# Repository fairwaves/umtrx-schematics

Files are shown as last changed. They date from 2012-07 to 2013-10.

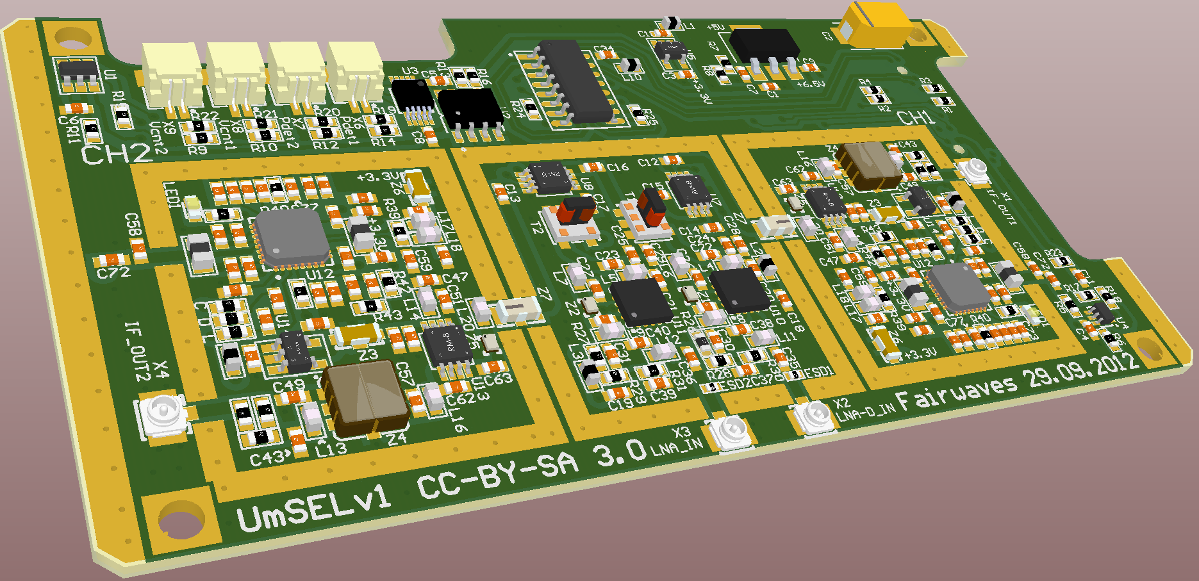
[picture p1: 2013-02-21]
umsel-v1/pictures/UmSELv1-TOP.png

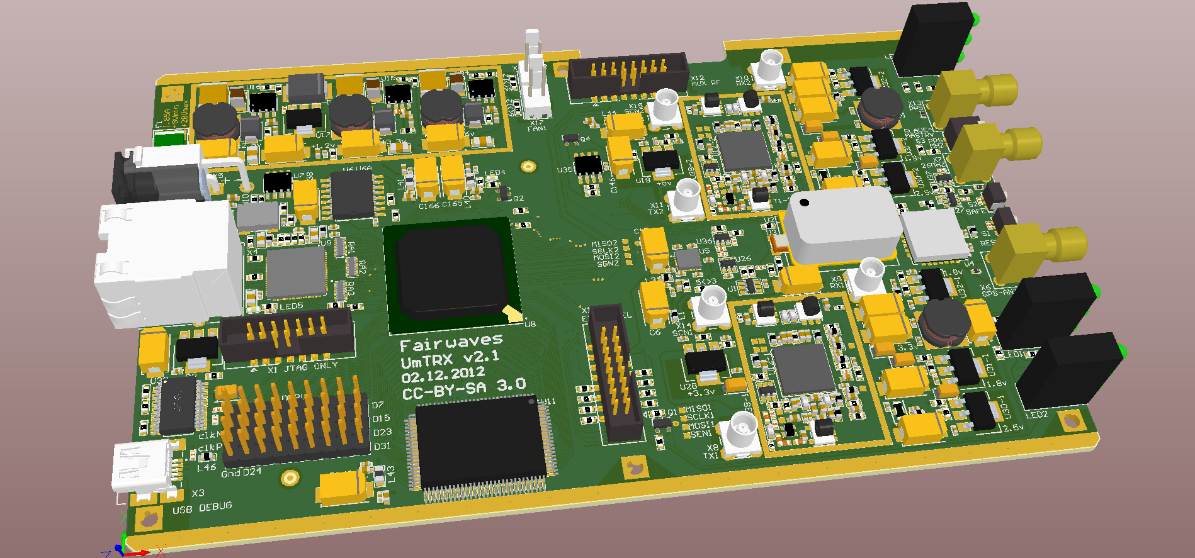
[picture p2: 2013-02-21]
umtrx-v2.1/pictures/UmTRXv21_all_comp.png

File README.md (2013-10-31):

Schematics and accompanying documentation for the UmTRX project
===============================================================

UmTRX is a dual-channel wide-band SDR transceiver with 1GbE connection. It is developed by [Fairwaves] team to be used as a transceiver for [OpenBTS] and [OsmoBTS] GSM base stations, but due to its SDR nature it could be used for many other applications as well.

For more details visit the project web-site: http://code.google.com/p/umtrx/

[Fairwaves]: http://www.fairwaves.ru/
[OpenBTS]: https://wush.net/trac/rangepublic/
[OsmoBTS]: http://openbsc.osmocom.org/trac/wiki/OsmoBTS

Structure
---------

- umtrx-v2 - files related to UmTRXv2 boards
  - altium - design files in Altium Designer format
  - bom - Bill of Materials exported from the Altium Designer
  - pdf - schematics and assembly drawings exported from the Altium Designer
  - pictures - 3D model pictures and photos
- umtrx-v2.1 - files related to UmTRXv2.1 boards
  - altium - design files in Altium Designer format
  - bom - Bill of Materials exported from the Altium Designer
  - pdf - schematics and assembly drawings exported from the Altium Designer
  - pictures - 3D model pictures and photos
- umsel-v1 - files related to UmSELv1 preselector mezzanine boards (GSM900 and GSM1800 versions)
  - altium - design files in Altium Designer format
  - bom - Bill of Materials exported from the Altium Designer
  - gerber - PCB layout in the Gerber format
  - NC Drill - drill files for manufacturing
  - pdf - schematics and assembly drawings exported from the Altium Designer
  - Pick Place - pick and place files for manufacturing
  - pictures - 3D model pictures and photos

Note: PCB layout for new UmTRX versions are published when we start selling this version. Prior to that it's available per request to our partners.

License
-------

All design files, including schematics and PCB layout are licensed under Creative Commons Attribution-ShareAlike 3.0 license [CC-BY-SA 3.0].

In few words, it means, that you're free to copy, distribute and adapt the work both for commercial and non-commercial use, under the condition that you attribute the original project and distribute the derived work under the same or a compatible license.

For a full legal text of the license please refer to the [Creative Commons web-site][CC-BY-SA 3.0].

**Note**: We're looking at the [CERN Open Hardware License][OHL] and will probably switch to it when dust settles around it a bit.

[CC-BY-SA 3.0]: http://creativecommons.org/licenses/by-sa/3.0/
[OHL]: http://www.ohwr.org/projects/cernohl/wiki/

Datasheets
----------

* Most datasheet are easily found at the respective manufacturers' web-sites.
* Datasheets for Lime Microsystems LMS6002D single-chip transceiver could be found at the Myriad-RF project LMS6002D-Docs GitHub repository: https://github.com/myriadrf/LMS6002D-docs

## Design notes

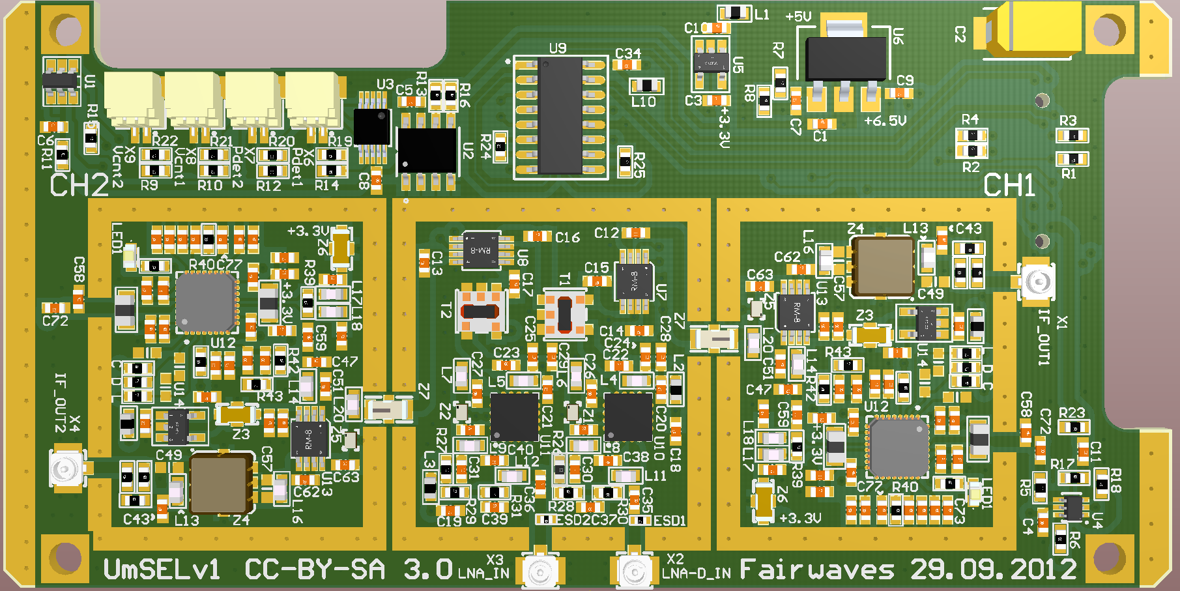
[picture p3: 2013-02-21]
umsel-v1/pictures/UmSELv1-TOP-1800.png

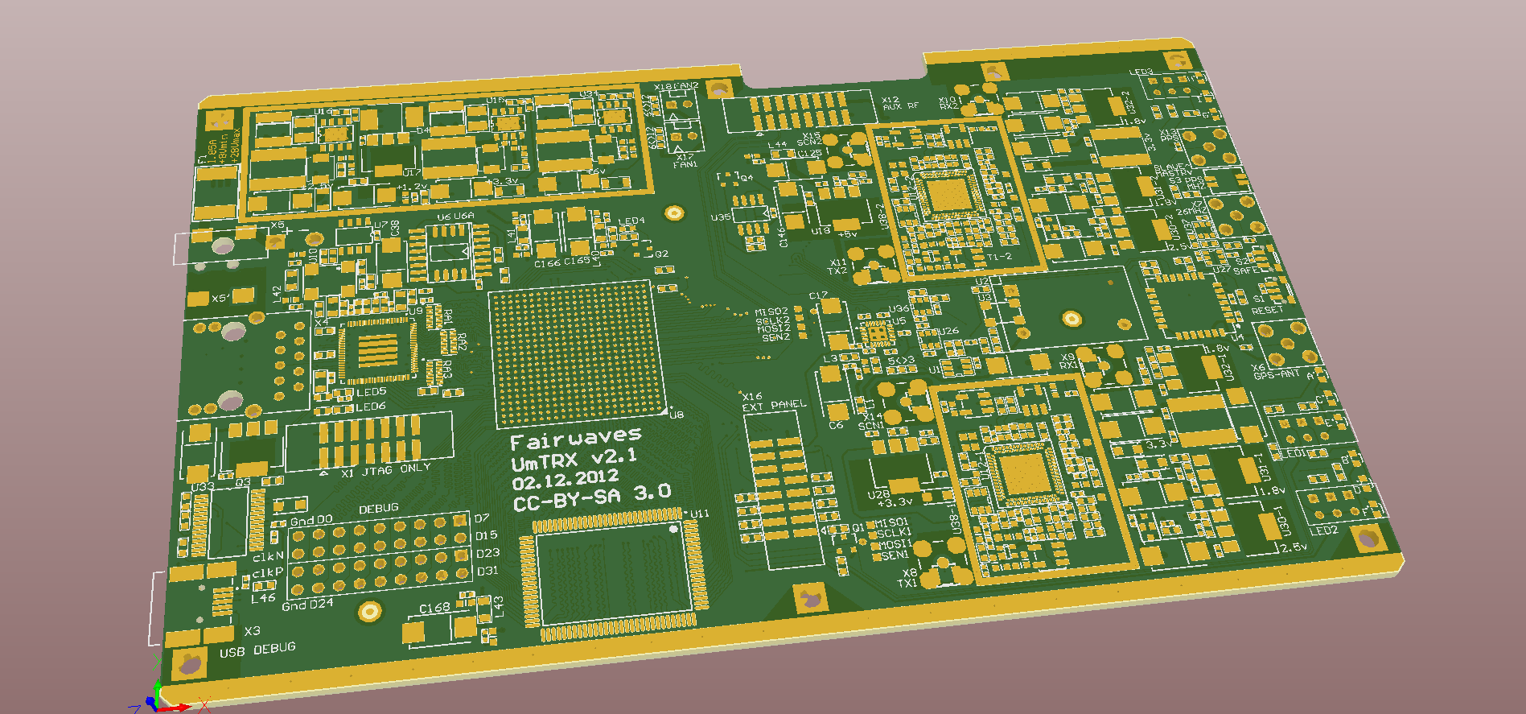
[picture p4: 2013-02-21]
umtrx-v2.1/pictures/UmTRXv21_empty.png

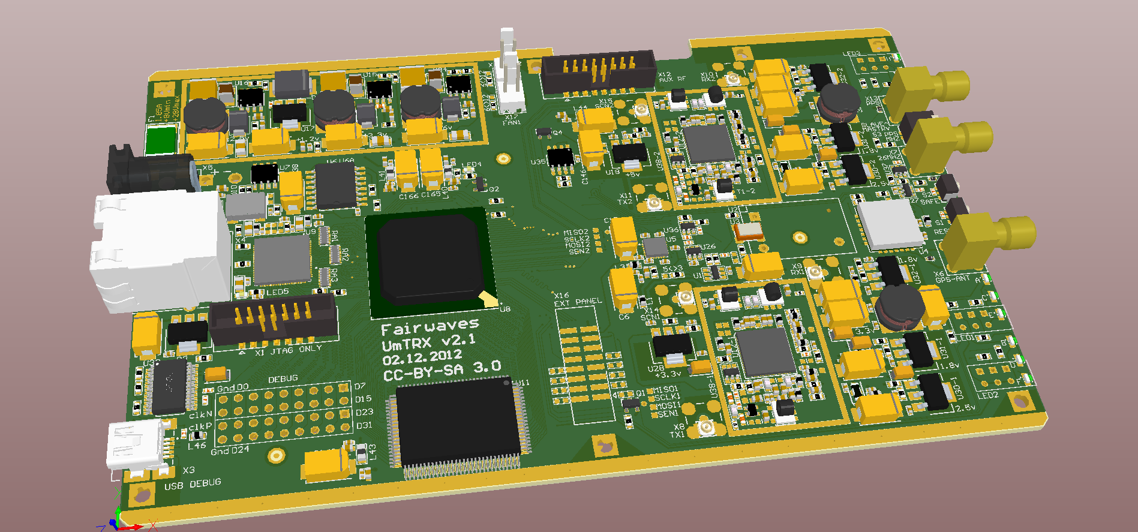
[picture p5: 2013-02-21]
umtrx-v2.1/pictures/UmTRXv21_20dBm_TCXO.png

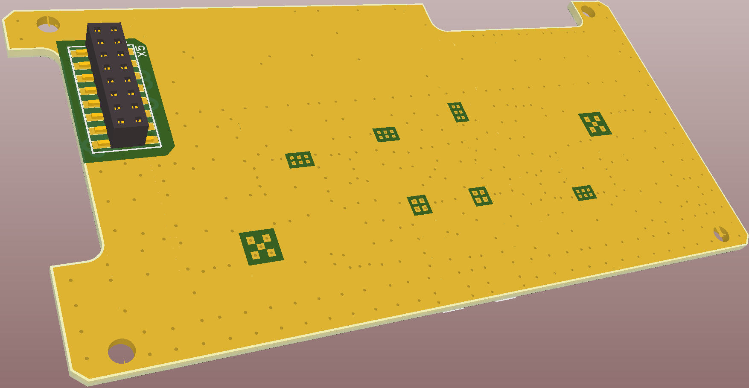
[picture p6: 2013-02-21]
umsel-v1/pictures/UmSELv1-BOT.png

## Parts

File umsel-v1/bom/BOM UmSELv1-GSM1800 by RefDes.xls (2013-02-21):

Designator | Value | Name | Description | Footprint
C1 | 0.1 | SMD0603 | Capacitor | C0603-Phillips
C2 | 100uF | CASE-D | Capacitor | cd7343
C3 | 1uF | SMD0603 | Capacitor | C0603-Phillips
C4 | 0.1 | SMD0603 | Capacitor | C0603-Phillips
C5 | 0.1 | SMD0603 | Capacitor | C0603-Phillips
C6 | 0.1 | SMD0603 | Capacitor | C0603-Phillips
C7 | 0.01 | SMD0603 | Capacitor | C0603-Phillips
C8 | 0.1 | SMD0603 | Capacitor | C0603-Phillips
C9 | 1uF | SMD0603 | Capacitor | C0603-Phillips
C10 | 1uF | SMD0603 | Capacitor | C0603-Phillips
C11 | 0.01 | SMD0603 | Capacitor | C0603-Phillips
C12 | 10p | SMD0603 | Capacitor | C0603-PHILLIPS
C13 | 10p | SMD0603 | Capacitor | C0603-PHILLIPS
C14 | 10p | SMD0603 | Capacitor | C0603-PHILLIPS
C15 | 10p | SMD0603 | Capacitor | C0603-PHILLIPS
C16 | 10p | SMD0603 | Capacitor | C0603-PHILLIPS
C17 | 10p | SMD0603 | Capacitor | C0603-PHILLIPS
C18 | 0.1 | SMD0603 | Capacitor | C0603-Phillips
C19 | 0.1 | SMD0603 | Capacitor | C0603-Phillips
C20 | 3.3p | SMD0603 | Capacitor | C0603-PHILLIPS
C21 | 3.3p | SMD0603 | Capacitor | C0603-PHILLIPS
C22 | 100p | SMD0603 | Capacitor | C0603-PHILLIPS
C23 | 100p | SMD0603 | Capacitor | C0603-PHILLIPS
C24 | 0.1 | SMD0603 | Capacitor | C0603-Phillips
C25 | 0.1 | SMD0603 | Capacitor | C0603-Phillips
C26 | 10p | SMD0603 | Capacitor | C0603-PHILLIPS
C27 | 10p | SMD0603 | Capacitor | C0603-PHILLIPS
C28 | 4.7uF | SMD0603 | Capacitor | C0603-Phillips
C29 | 4.7uF | SMD0603 | Capacitor | C0603-Phillips
C30 | 10p | SMD0603 | Capacitor | C0603-PHILLIPS
C31 | 10p | SMD0603 | Capacitor | C0603-PHILLIPS
C32 | 1000p | SMD0603 | Capacitor | C0603-PHILLIPS
C33 | 1000p | SMD0603 | Capacitor | C0603-PHILLIPS
C34 | 0.1 | SMD0603 | Capacitor | C0603-Phillips
C35 | 10p | SMD0603 | Capacitor | C0603-PHILLIPS
C36 | 10p | SMD0603 | Capacitor | C0603-PHILLIPS
C37 | 4.7uF | SMD0603 | Capacitor | C0603-Phillips
C38 | 10p | SMD0603 | Capacitor | C0603-Phillips
C39 | 4.7uF | SMD0603 | Capacitor | C0603-Phillips
C40 | 10p | SMD0603 | Capacitor | C0603-Phillips
C43 | 3.3pF | SMD0603 | Capacitor | C0603-Phillips
C43" | 3.3pF | SMD0603 | Capacitor | C0603-Phillips
C45 | 0.1 | SMD0603 | Capacitor | C0603-Phillips
C45" | 0.1 | SMD0603 | Capacitor | C0603-Phillips
C46 | 10p | SMD0603 | Capacitor | C0603-Phillips
C46" | 10p | SMD0603 | Capacitor | C0603-Phillips
C47 | 3p | SMD0603 | Capacitor | C0603-Phillips
C47" | 3p | SMD0603 | Capacitor | C0603-Phillips
C48 | 3300p | SMD0603 | Capacitor | C0603-Phillips
C48" | 3300p | SMD0603 | Capacitor | C0603-Phillips
C50 | 1000p | SMD0603 | Capacitor | C0603-Phillips
C50" | 1000p | SMD0603 | Capacitor | C0603-Phillips
C51 | 3p | SMD0603 | Capacitor | C0603-Phillips
C51" | 3p | SMD0603 | Capacitor | C0603-Phillips
C52 | 10p | SMD0603 | Capacitor | C0603-Phillips
C52" | 10p | SMD0603 | Capacitor | C0603-Phillips
C53 | 0.1 | SMD0603 | Capacitor | C0603-Phillips
C53" | 0.1 | SMD0603 | Capacitor | C0603-Phillips
C54 | 0.1 | SMD0603 | Capacitor | C0603-Phillips
C54" | 0.1 | SMD0603 | Capacitor | C0603-Phillips
C55 | 10p | SMD0603 | Capacitor | C0603-Phillips
C55" | 10p | SMD0603 | Capacitor | C0603-Phillips
C56 | 10p | SMD0603 | Capacitor | C0603-Phillips
C56" | 10p | SMD0603 | Capacitor | C0603-Phillips
C58 | 47p | SMD0603 | Capacitor | C0603-Phillips
C58" | 47p | SMD0603 | Capacitor | C0603-Phillips
C59 | 100p | SMD0603 | Capacitor | C0603-Phillips
C59" | 100p | SMD0603 | Capacitor | C0603-Phillips
C60 | 0.1 | SMD0603 | Capacitor | C0603-Phillips
C60" | 0.1 | SMD0603 | Capacitor | C0603-Phillips
C61 | 10p | SMD0603 | Capacitor | C0603-Phillips
C61" | 10p | SMD0603 | Capacitor | C0603-Phillips
C62 | 3.3pF | SMD0603 | Capacitor | C0603-Phillips
C62" | 3.3pF | SMD0603 | Capacitor | C0603-Phillips
C63 | 10p | SMD0603 | Capacitor | C0603-Phillips
C63" | 10p | SMD0603 | Capacitor | C0603-Phillips
C64 | 1uF | SMD0603 | Capacitor | C0603-Phillips
C64" | 1uF | SMD0603 | Capacitor | C0603-Phillips
C65 | 100p | SMD0603 | Capacitor | C0603-Phillips
C65" | 100p | SMD0603 | Capacitor | C0603-Phillips
C66 | 0.1 | SMD0603 | Capacitor | C0603-Phillips
C66" | 0.1 | SMD0603 | Capacitor | C0603-Phillips
C67 | 10p | SMD0603 | Capacitor | C0603-Phillips
C67" | 10p | SMD0603 | Capacitor | C0603-Phillips
C68 | 10p | SMD0603 | Capacitor | C0603-Phillips
C68" | 10p | SMD0603 | Capacitor | C0603-Phillips
C69 | 0.1 | SMD0603 | Capacitor | C0603-Phillips
C69" | 0.1 | SMD0603 | Capacitor | C0603-Phillips
C70 | 0.1 | SMD0603 | Capacitor | C0603-Phillips
C70" | 0.1 | SMD0603 | Capacitor | C0603-Phillips
C71 | 1uF | SMD0603 | Capacitor | C0603-Phillips
C71" | 1uF | SMD0603 | Capacitor | C0603-Phillips
C72 | 1000p | SMD0603 | Capacitor | C0603-Phillips
C72" | 1000p | SMD0603 | Capacitor | C0603-Phillips
C73 | 0.1 | SMD0603 | Capacitor | C0603-Phillips
C73" | 0.1 | SMD0603 | Capacitor | C0603-Phillips
C74 | 10p | SMD0603 | Capacitor | C0603-Phillips
C74" | 10p | SMD0603 | Capacitor | C0603-Phillips
C75 | 0.1 | SMD0603 | Capacitor | C0603-Phillips
C75" | 0.1 | SMD0603 | Capacitor | C0603-Phillips
C76 | 10p | SMD0603 | Capacitor | C0603-Phillips
C76" | 10p | SMD0603 | Capacitor | C0603-Phillips
C77 | 1500p | SMD0603 | Capacitor | C0603-Phillips
C77" | 1500p | SMD0603 | Capacitor | C0603-Phillips
C78 | 0.047uF | SMD0603 | Capacitor | C0603-Phillips
C78" | 0.047uF | SMD0603 | Capacitor | C0603-Phillips
C79 | 1uF | SMD0603 | Capacitor | C0603-Phillips
C79" | 1uF | SMD0603 | Capacitor | C0603-Phillips
ESD1 |  | SESD0402X1BN-0010-098 | ESD diod bi-directional | R0402-Phillips
ESD2 |  | SESD0402X1BN-0010-098 | ESD diod bi-directional | R0402-Phillips
L1 |  | TI160808U601 | Choke | Ti160808-Phillips
L2 |  | TI160808U601 | Choke | Ti160808-Phillips
L3 |  | TI160808U601 | Choke | Ti160808-Phillips
L4 | 4.7nH | TF160808 | Coil | TF160808-Phillips
L5 | 4.7nH | TF160808 | Coil | TF160808-Phillips
L6 | 12nH | TF160808 | Coil | TF160808-Phillips
L7 | 12nH | TF160808 | Coil | TF160808-Phillips
L8 | 100nH | TF160808 | Coil | TF160808-Phillips
L9 | 100nH | TF160808 | Coil | TF160808-Phillips
L10 |  | TI160808U601 | Choke | Ti160808-Phillips
L11 | 5.6nH | TF160808 | Coil | TF160808-Phillips
L12 | 5.6nH | TF160808 | Coil | TF160808-Phillips
L13 | 82nH | TF160808 | Coil | TF160808-Phillips
L13" | 82nH | TF160808 | Coil | TF160808-Phillips
L14 | 3.9nH | TF160808 | Coil | TF160808-Phillips
L14" | 3.9nH | TF160808 | Coil | TF160808-Phillips
L15 |  | TI201209U601 | Choke | TI2012-Phillips
L15" |  | TI201209U601 | Choke | TI2012-Phillips
L16 | 82nH | TF160808 | Coil | TF160808-Phillips
L16" | 82nH | TF160808 | Coil | TF160808-Phillips
L17 | 82nH | TF160808 | Coil | TF160808-Phillips
L17" | 82nH | TF160808 | Coil | TF160808-Phillips
L18 | 82nH | TF160808 | Coil | TF160808-Phillips
L18" | 82nH | TF160808 | Coil | TF160808-Phillips
L19 |  | TI201209U601 | Choke | TI2012-Phillips
L19" |  | TI201209U601 | Choke | TI2012-Phillips
L20 | 12nH | TF160808 | Coil | TF160808-Phillips
L20" | 12nH | TF160808 | Coil | TF160808-Phillips
L21 |  | TI160808U601 | Choke | Ti160808-Phillips
L21" |  | TI160808U601 | Choke | Ti160808-Phillips
LED1 |  | LS Q976-NR-1 | LED SMD | LED-0603y
LED1" |  | LS Q976-NR-1 | LED SMD | LED-0603y
R1 | 10k | SMD0603 | Resistor | R0603-PHILLIPS
R2 | 10k | SMD0603 | Resistor | R0603-PHILLIPS
R3 | 10k | SMD0603 | Resistor | R0603-PHILLIPS
R4 | 10k | SMD0603 | Resistor | R0603-PHILLIPS
R5 | 51 | SMD0603 | Resistor | R0603-PHILLIPS
R6 | 51 | SMD0603 | Resistor | R0603-PHILLIPS
R7 | 120 | SMD0603 | Resistor | R0603-PHILLIPS
R8 | 360 | SMD0603 | Resistor | R0603-PHILLIPS
R9 | 3k | SMD0603 | Resistor | R0603-PHILLIPS
R10 | 3k | SMD0603 | Resistor | R0603-PHILLIPS
R11 | 100 | SMD0603 | Resistor | R0603-PHILLIPS
R12 | 3k | SMD0603 | Resistor | R0603-PHILLIPS
R13 | 1k | SMD0603 | Resistor | R0603-PHILLIPS
R14 | 3k | SMD0603 | Resistor | R0603-PHILLIPS
R15 | 1k | SMD0603 | Resistor | R0603-PHILLIPS
R16 | 1k | SMD0603 | Resistor | R0603-PHILLIPS
R17 | 10k | SMD0603 | Resistor | R0603-PHILLIPS
R18 | 10k | SMD0603 | Resistor | R0603-PHILLIPS
R19 | 27K | SMD0603 | Resistor | R0603-PHILLIPS
R20 | 27K | SMD0603 | Resistor | R0603-PHILLIPS
R21 | 27K | SMD0603 | Resistor | R0603-PHILLIPS
R22 | 27K | SMD0603 | Resistor | R0603-PHILLIPS
R23 | 51 | SMD0603 | Resistor | R0603-PHILLIPS
R24 | 100 | SMD0603 | Resistor | R0603-PHILLIPS
R25 | 100 | SMD0603 | Resistor | R0603-PHILLIPS
R26 | 0 | SMD0603 | Resistor | R0603-PHILLIPS
R27 | 0 | SMD0603 | Resistor | R0603-PHILLIPS
R28 | 4k7 | SMD0603 | Resistor | R0603-PHILLIPS
R29 | 4k7 | SMD0603 | Resistor | R0603-PHILLIPS
R30 | 51 | SMD0603 | Resistor | R0603-PHILLIPS
R31 | 51 | SMD0603 | Resistor | R0603-PHILLIPS
R32 | 100 | SMD0603 | Resistor | R0603-PHILLIPS
R32" | 100 | SMD0603 | Resistor | R0603-PHILLIPS
R33 | 100 | SMD0603 | Resistor | R0603-PHILLIPS
R33" | 100 | SMD0603 | Resistor | R0603-PHILLIPS
R34 | 100 | SMD0603 | Resistor | R0603-PHILLIPS
R34" | 100 | SMD0603 | Resistor | R0603-PHILLIPS
R35 | 430 | SMD0603 | Resistor | R0603-PHILLIPS
R35" | 430 | SMD0603 | Resistor | R0603-PHILLIPS
R36 | 12 | SMD0603 | Resistor | R0603-PHILLIPS
R36" | 12 | SMD0603 | Resistor | R0603-PHILLIPS
R37 | 430 | SMD0603 | Resistor | R0603-PHILLIPS
R37" | 430 | SMD0603 | Resistor | R0603-PHILLIPS
R38 | 10k | SMD0603 | Resistor | R0603-PHILLIPS
R38" | 10k | SMD0603 | Resistor | R0603-PHILLIPS
R39 | 100 | SMD0603 | Resistor | R0603-PHILLIPS
R39" | 100 | SMD0603 | Resistor | R0603-PHILLIPS
R40 | 4k7 | SMD0603 | Resistor | R0603-PHILLIPS
R40" | 4k7 | SMD0603 | Resistor | R0603-PHILLIPS
R41 | 1k | SMD0603 | Resistor | R0603-PHILLIPS
R41" | 1k | SMD0603 | Resistor | R0603-PHILLIPS
R42 | 620 | SMD0603 | Resistor | R0603-PHILLIPS
R42" | 620 | SMD0603 | Resistor | R0603-PHILLIPS
R43 | 300 | SMD0603 | Resistor | R0603-PHILLIPS
R43" | 300 | SMD0603 | Resistor | R0603-PHILLIPS
T1 |  | SBTC-2-20L | Transformer | AT1030
T2 |  | SBTC-2-20L | Transformer | AT1030
U1 |  | TMP102 | IC | PDSO-G6
U2 |  | 24LC024SN | EEPROM | SOIC8
U3 |  | ADS1015 | IC | TSSOP-SPDSO-G10
U4 |  | NC7WZ16P6X | IC | SC70-6LD(SOT363)
U5 |  | ADP151AUJZ-3.3 | IC | SOT-23-5[3.1x1.8/0.95]
U6 |  | LD1117S | IC | SOT-223-1
U7 |  | HMC435MS8G | IC | MS8G
U8 |  | HMC435MS8G | IC | MS8G
U9 |  | DS90C032/FIN1532 | IC | SOIC16
U10 |  | MGA13216 | IC | MGA13x16(GND NC Legs)
U11 |  | MGA13216 | IC | MGA13x16(GND NC Legs)
U12 |  | ADF4350BCPZ | IC | CP-32-2
U12" |  | ADF4350BCPZ | IC | CP-32-2
U13 |  | HMC485MS8G | IC | MS8G
U13" |  | HMC485MS8G | IC | MS8G
U14 |  | ADP151AUJZ-3.3 | IC | SOT-23-5[3.1x1.8/0.95]
U14" |  | ADP151AUJZ-3.3 | IC | SOT-23-5[3.1x1.8/0.95]
X1 |  | 1566230-1 | Connector (UMCC) | U_FL
X2 |  | 1566230-1 | Connector (UMCC) | U_FL
X3 |  | 1566230-1 | Connector (UMCC) | U_FL
X4 |  | 1566230-1 | Connector (UMCC) | U_FL
X5 |  | NPPN082FFKP(S)-RC | Connector female 2mm SMD | NPPN082FFKP(S)
X6 |  | SM02B-SRSS-TB | Connector | SM02B-SRSS-TB
X7 |  | SM02B-SRSS-TB | Connector | SM02B-SRSS-TB
X8 |  | SM02B-SRSS-TB | Connector | SM02B-SRSS-TB
X9 |  | SM02B-SRSS-TB | Connector | SM02B-SRSS-TB
Z1 |  | FAR-F6KA-1G7475-D4CY | SAW Filter | SAW-1.4x1x0.5mm
Z2 |  | FAR-F6KA-1G7475-D4CY | SAW Filter | SAW-1.4x1x0.5mm
Z3 | 22nF | NFM3DCC223R1H3 | EMI_FILTER | NFM3DC
Z3" | 22nF | NFM3DCC223R1H3 | EMI_FILTER | NFM3DC
Z4 |  | TB0130A | SAW filter | DCC8_5x5
Z4" |  | TB0130A | SAW filter | DCC8_5x5
Z5 |  | FAR-F6KA-1G7475-D4CY | SAW Filter | SAW-1.4x1x0.5mm
Z5" |  | FAR-F6KA-1G7475-D4CY | SAW Filter | SAW-1.4x1x0.5mm
Z6 | 22nF | NFM3DCC223R1H3 | EMI_FILTER | NFM3DC
Z6" | 22nF | NFM3DCC223R1H3 | EMI_FILTER | NFM3DC
Z7 | HFCN-740+ | HFCN-740+ | High pass filter | LFCN-HFCN
Z7" | HFCN-740+ | HFCN-740+ | High pass filter | LFCN-HFCN

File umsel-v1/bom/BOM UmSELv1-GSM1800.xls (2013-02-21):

Description | Comment | Footprint | Designator | Quantity | Manufacturer
Capacitor | 0.01 | C0603 | C7, C11 | 2 | MURATA
Capacitor | 0.047uF | C0603 | C78, C78" | 2 | MURATA
Capacitor | 0.1 | C0603 | C1, C4, C5, C6, C8, C18, C19, C24, C25, C34, C45, C45", C53, C53", C54, C54", C60, C60", C66, C66", C69, C69", C70, C70", C73, C73", C75, C75" | 28 | MURATA
Capacitor | 1000p | C0603 | C50, C50", C72, C72" | 4 | MURATA
Capacitor | 1000p | C0603 | C32, C33 | 2 | MURATA
Capacitor | 100p | C0603 | C59, C59", C65, C65" | 4 | MURATA
Capacitor | 100p | C0603 | C22, C23 | 2 | MURATA
Capacitor | 100uF | CD7343 | C2 | 1 | SPRAGUE
Capacitor | 10p | C0603 | C46, C46", C52, C52", C56, C56", C61, C61", C67, C67", C68, C68", C74, C74", C76, C76" | 16 | MURATA
Capacitor | 10p | C0603 | C38, C40 | 2 | MURATA
Capacitor | 10p | C0603 | C12, C13, C14, C15, C16, C17, C26, C27, C30, C31, C35, C36, C55, C55", C63, C63" | 16 | MURATA
Capacitor | 1500p | C0603 | C77, C77" | 2 | MURATA
Capacitor | 1uF | C0603 | C3, C9, C10, C64, C64", C71, C71", C79, C79" | 9 | MURATA
Capacitor | 3.3p | C0603 | C20, C21 | 2 | MURATA
Capacitor | 3.3pF | C0603 | C43, C43", C62, C62" | 4 | MURATA
Capacitor | 3300p | C0603 | C48, C48" | 2 | MURATA
Capacitor | 3p | C0603 | C47, C47", C51, C51" | 4 | MURATA
Capacitor | 4.7uF | C0603 | C28, C29, C37, C39 | 4 | MURATA
Capacitor | 47p | C0603 | C58, C58" | 2 | MURATA
Choke | TI160808U601 | TI160808 | L1, L2, L3, L10, L21, L21" | 6 | MURATA
Choke | TI201209U601 | TI201209 | L15, L15", L19, L19" | 4 | MURATA
Coil | 100nH | TF160808 | L8, L9 | 2 | SMD
Coil | 12nH | TF160808 | L6, L7, L20, L20" | 4 | SMD
Coil | 3.9nH | TF160808 | L14, L14" | 2 | SMD
Coil | 4.7nH | TF160808 | L4, L5 | 2 | SMD
Coil | 5.6nH | TF160808 | L11, L12 | 2 | SMD
Coil | 82nH | TF160808 | L13, L13", L16, L16", L17, L17", L18, L18" | 8 | SMD
Connector | SM02B-SRSS-TB | SM02B-SRSS-TB | X6, X7, X8, X9 | 4 | JST
Connector (UMCC) | 1566230-1 | U_FL | X1, X2, X3, X4 | 4 | Tyco El Corp
Connector female 2mm SMD | NPPN082FFKP(S)-RC | NPPN082FFKP(S) | X5 | 1 | Sullins
EEPROM | 24LC024SN | SOIC8 | U2 | 1 | Microchip
EMI_FILTER | NFM3DCC223R1H3 | NFM3DC | Z3, Z3", Z6, Z6" | 4 | Murata
ESD diod bi-directional | SESD0402X1BN-0010-098 | SESD0402X | ESD1, ESD2 | 2 | Tyco El Corp
High pass filter | HFCN-740+ | LFCN-HFCN | Z7, Z7" | 2 | MiniCircuits
IC | ADF4350BCPZ | CP-32-2 | U12, U12" | 2 | Analog Devices
IC | ADP151AUJZ-3.3 | SOT-23-5 | U5, U14, U14" | 3 | AD
IC | ADS1015 | TSSOP-SPDSO-G10 | U3 | 1 | TI
IC | DS90C032/FIN1532 | SOIC16 | U9 | 1 | National/Fairchild
IC | HMC435MS8G | MS8G | U7, U8 | 2 | Hittite
IC | HMC483_5MS8G | MS8G | U13, U13" | 2 | Hittite
IC | LD1117S | SOT-223-1 | U6 | 1 | STMicro
IC | MGA13?16 | MGA13x16 | U10, U11 | 2 | AVAGO
IC | NC7WZ16P6X | SC70-6LD(SOT363) | U4 | 1 | Fairchild
IC | TMP102 | PDSO-G6 | U1 | 1 | TI
LED SMD | LS Q976-NR-1 | LED0603 | LED1, LED1" | 2 | OSRAM Opto Semi
Resistor | 0 | R0603 | R26, R27 | 2 | YAGEO
Resistor | 100 | R0603 | R11, R24, R25, R32, R32", R33, R33", R34, R34", R39, R39" | 11 | YAGEO
Resistor | 10k | R0603 | R1, R2, R3, R4, R17, R18, R38, R38" | 8 | YAGEO
Resistor | 12 | R0603 | R36, R36" | 2 | YAGEO
Resistor | 120 | R0603 | R7 | 1 | YAGEO
Resistor | 1k | R0603 | R13, R15, R16, R41, R41" | 5 | YAGEO
Resistor | 27K | R0603 | R19, R20, R21, R22 | 4 | YAGEO
Resistor | 300 | R0603 | R43, R43" | 2 | YAGEO
Resistor | 360 | R0603 | R8 | 1 | YAGEO
Resistor | 3k | R0603 | R9, R10, R12, R14 | 4 | YAGEO
Resistor | 430 | R0603 | R35, R35", R37, R37" | 4 | YAGEO
Resistor | 4k7 | R0603 | R40, R40" | 2 | YAGEO
Resistor | 4k7 | R0603 | R28, R29 | 2 | YAGEO
Resistor | 51 | R0603 | R30, R31 | 2 | YAGEO
Resistor | 51 | R0603 | R5, R6, R23 | 3 | YAGEO
Resistor | 620 | R0603 | R42, R42" | 2 | YAGEO
SAW Filter | FAR-F6KA-1G7475-D4CY | SAW-1.4x1x0.5mm | Z1, Z2, Z5, Z5" | 4 | Taiyo Yuden
SAW filter | TB0130A | DCC8_5x5 | Z4, Z4" | 2 | Tai-SAW
Transformer | SBTC-2-20L | AT1030 | T1, T2 | 2 | Mini-Cirquits
Wire Connector | 02SR-3S |  |  | 4 | JST

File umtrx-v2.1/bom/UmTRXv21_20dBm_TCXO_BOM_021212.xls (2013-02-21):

SMD components
Description | Name | Value | U/P/TKE | Footprint | Designator | Quantity | Pins | Total | Link | Manufacturer
ESD diod bi-directional | SESD0402X1BN-0010-098 |  | 9.8V | SMD0402 | ESD3-1, ESD3-2, ESD4-1, ESD4-2, ESD5-1, ESD5-2 | 6 | 2 | 12 | SESD0402X1BN-0010-098CT-ND (http://www.digikey.com/product-detail/en/SESD0402X1BN-0010-098/SESD0402X1BN-0010-098CT-ND/2834924) | Tyco Electronics Corp
ESD diod unidirectional | SESD0402S-005-054 |  | 5.4V | SMD0402 | ESD1, ESD2, ESD3 | 3 | 2 | 6 | SESD0402S-005-054CT-ND (http://www.digikey.com/product-detail/en/SESD0402S-005-054/SESD0402S-005-054CT-ND/2178154) | Tyco Electronics Corp
FUSE PTC resetable | 0ZCD0185FF2C |  | 33V/1.85A | FUSE2920 | F1 | 1 | 2 | 2 | 507-1370-1-ND (http://www.digikey.com/product-detail/en/0ZCD0185FF2C/507-1370-1-ND/1560237) | Bel Fuse
Switch 2pos Piano SMD right angle | CHP-021TA |  |  | CHP-02xA | S3 | 1 | 4 | 4 | 563-1015-1-ND (http://www.digikey.com/product-detail/en/CHP-021TA/563-1015-1-ND/948409) | Copal Electronics
Switch Tactile SMD right angle | TL3340AF160QG |  |  | TL3340 | S1, S2 | 2 | 4 | 8 | EG4627CT-ND (http://www.digikey.com/product-detail/en/TL3340AF160QG/EG4627CT-ND/1885974) | E-Switch
TCVCXO | TCD4029-26.0M | 25MHz | 100ppb | TCXO5X3 | U3 | 1 | 4 | 4 |  | Pletronics
TCXO | FNETHE025 | 25MHz |  | TCXO7x5 | U10 | 1 | 4 | 4 |  | Saronix-eCera
TVS Diod | LNBTVS4-304S |  |  | SMC | D4 | 1 | 2 | 2 | 497-12495-1-ND (http://www.digikey.com/product-detail/en/LNBTVS4-304S/497-12495-1-ND/2864662) | ST
Diod schottky | STPS3L60U |  |  | SMB | D1, D2, D3 | 3 | 2 | 6 | 497-6584-1-ND (http://www.digikey.com/product-detail/en/STPS3L60U/497-6584-1-ND/1865306) | ST
Ferrite choke | MLB-160808-0600PL | 600 Ohm |  | 160808 (0603) | L1, L2, L3, L4, L5, L8-1, L8-2, L9-1, L9-2, L10-1, L10-2, L11-1, L11-2, L12-1, L12-2, L13-1, L13-2, L14-1, L14-2, L15-1, L15-2, L16-1, L16-2, L17-1, L17-2, L18-1, L18-2, L19-1, L19-2, L20-1, L20-2, L21-1, L21-2, L22-1, L22-2, L23-1, L23-2, L24-1, L24-2, L25-1, L25-2, L26-1, L26-2, L27-1, L27-2, L28-1, L28-2, L29-1, L29-2, L45, L46 | 51 | 2 | 102 | MLB-160808-0600PL (http://ru.farnell.com/mec-marcom/mlb-160808-0600pl/ferrite-bead-0603-case-600ohm-1a/dp/1308770RL) | KE KITAGAWA
Ferrite choke | MLB-201209-0120PU | 120 Ohm |  | 201209 (0805) | L40, L41, L42, L43, L44 | 5 | 2 | 10 | MLB-201209-0120PU (http://ru.farnell.com/mec-marcom/mlb-201209-0120pu/ferrite-bead-0805-case-120ohm-5a/dp/1308778RL) | KE KITAGAWA
Coil | SRN8040-150M | 15 uH |  | SRN8040 | L35, L36, L37, L7-1, L7-2 | 5 | 2 | 10 | SRN8040-150MCT-ND (http://www.digikey.com/product-detail/en/SRN8040-150M/SRN8040-150MCT-ND/2756181) | BOURNS
Coil | TF160808 | 39nH |  | 160808 | L30-1, L30-2, L31-1, L31-2, L34-1, L34-2 | 6 | 2 | 12 |  | SMD
Coil | TF160808 | 4,7nH |  | 160808 | L32-1, L32-2, L33-1, L33-2 | 4 | 2 | 8 |  | SMD
Cap MLCC | C5750Y5V1H226Z | 22uF/50V | Y5V | C2220 | C114, C115, C116 | 3 | 2 | 6 | 445-3487-1-ND (http://www.digikey.com/product-detail/en/C5750Y5V1H226Z/445-3487-1-ND/1801586) | TDK
Cap Tantal |  | 10uF | 10V | Case A | C12, C64-1, C64-2, C65-1, C65-2, C66-1, C66-2, C298 | 8 | 2 | 16 |  | SPRAGUE
Cap Tantal |  | 330uF | 10V | CASE-D | C9, C131, C140, C141, C169-1, C169-2 | 6 | 2 | 12 |  | Kemet
Cap Tantal |  | 100uF | 16V | CASE-D | C6, C17, C38, C51-1, C51-2, C52-1, C52-2, C53-1, C53-2, C54-1, C54-2, C125, C138, C146, C165, C166, C168, C171 | 18 | 2 | 36 |  | SPRAGUE
Cap ceram |  | 0.01 | Y5V | SMD0402 | C33, C34, C35, C36, C37, C135, C146-1, C146-2, C297 | 9 | 2 | 18 |  | MURATA
Cap ceram |  | 0.1 | Y5V | SMD0402 | C4, C5, C7, C8, C10, C13, C14, C15, C18, C20, C21, C22, C24, C25, C26, C27, C39, C40, C42, C43, C44-1, C44-2, C47-1, C47-2, C48-1, C48-2, C49-1, C49-2, C50-1, C50-2, C55-1, C55-2, C56-1, C56-2, C57-1, C57-2, C58-1, C58-2, C59-1, C59-2, C60-1, C60-2, C61-1, C61-2, C62-1, C62-2, C63-1, C63-2, C67-1, C67-2, C69-1, C69-2, C70-1, C70-2, C71-1, C71-2, C72-1, C72-2, C78-1, C78-2, C79-1, C79-2, C80-1, C80-2, C85-1, C85-2, C86-1, C86-2, C87-1, C87-2, C88-1, C88-2, C89-1, C89-2, C90-1, C90-2, C91-1, C91-2, C92-1, C92-2, C93-1, C93-2, C94-1, C94-2, C113, C120, C127, C139, C143, C144, C145, C147, C148, C156, C157, C158, C159, C172, C174, C175, C176, C177, C178, C179, C180, C181, C182, C183, C184, C185, C186, C187, C188, C189, C190, C191, C192, C193, C194, C196, C197, C198, C199, C200, C201, C202, C203, C204, C205, C206, C207, C208, C209, C210, C211, C212, C213, C215, C216, C217, C218, C219, C220, C221, C222, C223, C224, C225, C227, C229, C230, C231, C232, C233, C234, C235, C236, C237, C238, C239, C240, C241, C242, C243, C244, C245, C270, C271, C272, C273, C274, C275, C276, C277, C278, C280, C281, C282, C289, C290, C291, C292, C293, C294, C295, C296, C299, C300 | 188 | 2 | 376 |  | MURATA
Cap ceram |  | 2.2 | Y5V | SMD0402 | C11, C214, C228, C246, C247, C248, C249, C250, C251, C252, C254, C255, C256, C257, C258, C259, C260, C262, C263, C264, C265, C268, C279, C286, C287 | 25 | 2 | 50 |  | MURATA
Cap ceram |  | 1.0uF CER | Y5V | SMD0603 | C32, C41, C68-1, C68-2, C74-1, C74-2, C76-1, C76-2, C77-1, C77-2, C81-1, C81-2 | 12 | 2 | 24 |  | MURATA
Cap MLCC |  | 10.0uF CER | Y5V | SMD0603 | C73-1, C73-2, C75-1, C75-2 | 4 | 2 | 8 |  | MURATA
Cap ceram |  | 100p | NP0 | SMD0603 | C23, C82-1, C82-2, C98-1, C98-2, C95-1, C95-2, C100-1, C100-2, C101-1, C101-2, C102-1, C102-2, C103-1, C103-2, C104-1, C104-2, C105-1, C105-2, C106-1, C106-2, C107-1, C107-2, C110-1, C110-2, C111-1, C111-2, C112-1, C112-2 | 29 | 2 | 58 |  | MURATA
Cap ceram |  | 33p | NP0 | SMD0603 | C84-1, C84-2, C97-1, C97-2 | 4 | 2 | 8 |  | MURATA
Cap ceram |  | 220p | NP0 | SMD0603 | C19, C128, C129, C150, C151, C152, C153, C154, C161, C162, C163, C164, C266, C269 | 14 | 2 | 28 |  | MURATA
Cap ceram |  | 22n | X7R | SMD0603 | C132, C133, C267 | 3 | 2 | 6 |  | MURATA
Cap ceram |  | 1500p | NP0 | SMD0603 | C83-1, C83-2, C99-1, C99-2 | 4 | 2 | 8 |  | MURATA
Cap ceram |  | 3p | NP0 | SMD0603 | C96'-1, C96'-2 | 2 | 2 | 4 |  | MURATA
Cap MLCC |  | 33uF CER | Y5R | SMD0805 | C283, C284, C285 | 3 | 2 | 6 |  | MURATA
Cap MLCC | UMK316AB7475KL-T | 4,7uF | Y5V 50V | SMD1206 | C136, C137, C261 | 3 | 2 | 6 | 587-2994-1-ND (http://www.digikey.com/product-detail/en/UMK316AB7475KL-T/587-2994-1-ND/2714187) | Taiyo Yuden
Cap MLCC | UMK325 BJ106MM | 10uF/50V | X5R | SMD1210 | C117, C118, C119 | 3 | 2 | 6 | 587-2225-1-ND (http://www.digikey.com/product-detail/en/UMK325BJ106MM-T/587-2225-1-ND/2002923) | Taiyo Yuden
IC Spartan-6 LX FPGA | XC6SLX75-2FGG484C |  |  | FBGA484 | U8 | 1 | 484 | 484 |  | Xilinx
IC temperature sensor I2C | TMP102AIDRL |  |  | PDSO-G6 | U38-1, U38-2 | 2 | 6 | 12 | 296-22055-6-ND (http://www.digikey.com/product-detail/en/TMP102AIDRLT/296-22055-6-ND/1947267) | TI
IC EEPROM | 24LC024SN |  |  | SOIC8 | U7 | 1 | 8 | 8 |  | Microchip
IC SRAM | IS61NLP51236-200TQLI |  |  | QFP-100_20X14 | U11 | 1 | 100 | 100 | IS61NLP51236-200TQLI (http://www.digikey.com/product-detail/en/IS61NLP51236-200TQLI/706-1103-ND/1557418) | ISSI
IC DAC | DAC121S101CIMK |  |  | SOT-23-6 | U1 | 1 | 6 | 6 |  | National Semiconductor
IC GPS Receiver | EB-570 |  |  | EB-570 | U4 | 1 | 28 | 28 |  | Transystem Inc.
IC GBEth Phy | ET1011C2-CI-DT |  |  | QFN-84 | U9 | 1 | 85 | 85 |  | LSI
IC USB-UART Bridge | FT232RL |  |  | SSOP-28 | U33 | 1 | 28 | 28 |  | FTDI
IC DC/DC converter | L5973AD |  |  | SOIC8 - PWRPAD | U15, U16, U34 | 3 | 9 | 27 |  | ST
IC LDO linear regulator | LD1117S |  |  | SOT-223-1 | U17, U18, U28, U30-1, U30-2, U31-1, U31-2, U32-1, U32-2 | 9 | 3 | 27 |  | STMicro
IC RF transceiver | LMS6002D |  |  | DQFN120_9x9 | U12-1, U12-2 | 2 | 117 | 234 |  | Lime Microsystems
IC FLASH | M25P64-VMF6P |  |  | SO-16W | U6A | 1 | 8 | 8 | M25P64-VMF6P (http://ru.farnell.com/micron/m25p64-vmf6p/ic-srl-flash-64mbit-lv-16so/dp/1703285) | Micron
IC FAN controller | MAX6665ASA |  |  | SO-8 | U35 | 1 | 8 | 8 |  | Maxim
IC Clock distributor | Si5330F-A00215-GM |  |  | QFN-24 | U5 | 1 | 25 | 25 |  | Silicon Laboratoryes
IC Bidir buffer/level shifter | SN74LVC1T45DBV |  |  | SOT-23-6 | U26, U27, U36, U37 | 4 | 6 | 24 |  | TI
IC RF gain block | SPF-5043Z |  |  | SOT-343 | U14-1, U14-2 | 2 | 4 | 8 |  | RFMD
Connector SMD for ribbon cable | SBH21-NBPN-D07-SM-BK |  |  | SBH-14 | X1 | 1 | 14 | 14 | S9037-ND (http://www.digikey.com/product-detail/en/SBH21-NBPN-D07-SM-BK/S9037-ND/1989770) | Sullins
Connector Mini-USBB | 67503-1020 |  |  | USB/SM0.8-6H5 | X3 | 1 | 5 | 5 | WM5461CT-ND (http://www.digikey.com/product-detail/en/67503-1020/WM5461CT-ND/1624427) | Molex Inc
Connector SMD for ribbon cable | SBH21-NBPN-D08-SM-BK |  |  | SBH-16 | X12 | 1 | 16 | 16 | S9038-ND (http://www.digikey.com/product-detail/en/SBH21-NBPN-D08-SM-BK/S9038-ND/1989771) | Sullins
Connector UMCC (U.FL) | 1566230-1 |  |  | U_FL | X8, X9, X10, X11, X14, X15 | 6 | 3 | 18 | A36237CT-ND (http://www.digikey.com/product-detail/en/1566230-1/A36237CT-ND/1530698) | Tyco Electronics Corp
Connector coaxial | 1-1337582-0 |  |  | SMA-RIGHT ANGLE | X6, X7, X13 | 3 | 5 | 15 | SMA-RIGHT ANGLE (http://www.rfsupplier.com/thru-hole-jack-right-angle-mount-long-version-p-1876.html) | Tyco Electronics Corp
Connector Barrel Power Jack | PJ-002AH-SMT |  | -40`C | SMT | X5' | 1 | 4 |  | CP-002AHPJDKR-ND (http://www.digikey.com/product-detail/en/PJ-002AH-SMT/CP-002AHPJDKR-ND/1819769) | CUI Inc
Resistor |  | 0 | 0.1W | SMD0603 | R3, R7, R9, R41, R42, R124, R133, R165, R166, R172, R172' | 11 | 2 | 22 |  | YAGEO
Resistor |  | 10 | 0.1W | SMD0603 | R14, R15, R16, R17, R80-1, R80-2, R105-1, R105-2, R177-1, R177-2 | 10 | 2 | 20 |  | YAGEO
Resistor |  | 100 | 0.1W | SMD0603 | R43 | 1 | 2 | 2 |  | YAGEO
Resistor |  | 10k | 0.1W | SMD0603 | R18, R19, R20, R21, R46, R66, R122, R123, R154, R155, R156, R157, R173, R174 | 14 | 2 | 28 |  | YAGEO
Resistor |  | 120 | 0.1W | SMD0603 | R8, R96-1, R96-2, R99-1, R99-2, R100-1, R100-2, R101-1, R101-2, R134, R138 | 11 | 2 | 22 |  | YAGEO
Resistor |  | 12k | 0.1W | SMD0603 | R108-1, R108-2 | 2 | 2 | 4 |  | YAGEO
Resistor |  | 150 | 0.1W | SMD0603 | R103-1, R103-2, R104-1, R104-2 | 4 | 2 | 8 |  | YAGEO
Resistor |  | 1k | 0.1W | SMD0603 | R4, R11, R26, R27, R29, R33, R34, R35, R36, R37, R38, R64, R65, R78, R94, R95-1, R95-2, R153, R159, R162, R163, R164 | 22 | 2 | 44 |  | YAGEO
Resistor |  | 1k00 | 0.1W | SMD0603 | R61 | 1 | 2 | 2 |  | YAGEO
Resistor |  | 1k2 | 0.1W | SMD0603 | R168 | 1 | 2 | 2 |  | YAGEO
Resistor |  | 1k5 | 0.1W | SMD0603 | R67 | 1 | 2 | 2 |  | YAGEO
Resistor |  | 200 | 0.1W | SMD0603 | R5 | 1 | 2 | 2 |  | YAGEO
Resistor |  | 2k | 0.1W | SMD0603 | R91, R92 | 2 | 2 | 4 |  | YAGEO
Resistor |  | 2k2 | 0.1W | SMD0603 | R106-1, R106-2, R121-1, R121-2 | 4 | 2 | 8 |  | YAGEO
Resistor |  | 2k4 | 0.1W | SMD0603 | R152 | 1 | 2 | 2 |  | YAGEO
Resistor |  | 33 | 0.1W | SMD0603 | R89, R90 | 2 | 2 | 4 |  | YAGEO
Resistor |  | 330 | 0.1W | SMD0603 | R1, R13, R28, R31, R32, R55, R56, R57, R63, R149 | 10 | 2 | 20 |  | YAGEO
Resistor |  | 360 | 0.1W | SMD0603 | R135 | 1 | 2 | 2 |  | YAGEO
Resistor |  | 390 | 0.1W | SMD0603 | R107-1, R107-2 | 2 | 2 | 4 |  | YAGEO
Resistor |  | 3k3 | 0.1W | SMD0603 | R109-1, R109-2, R119-1, R119-2, R128 | 5 | 2 | 10 |  | YAGEO
Resistor |  | 4k7 | 0.1W | SMD0603 | R22, R23, R24, R30, R93, R129, R131, R132, R169, R170 | 10 | 2 | 20 |  | YAGEO
Resistor |  | 51 | 0.1W | SMD0603 | R45, R47, R48, R49, R50, R51, R58, R59, R110-1, R110-2, R111-1, R111-2, R112-1, R112-2, R113-1, R113-2 | 16 | 2 | 32 |  | YAGEO
Resistor |  | 56 | 0.1W | SMD0603 | R44, R97-1, R97-2, R98-1, R98-2 | 5 | 2 | 10 |  | YAGEO
Resistor |  | 5k1 | 0.1W | SMD0603 | R137 | 1 | 2 | 2 |  | YAGEO
Resistor |  | 5k6 | 0.1W | SMD0603 | R136 | 1 | 2 | 2 |  | YAGEO
Resistor |  | 6k34 | 0.1W | SMD0603 | R60 | 1 | 2 | 2 |  | YAGEO
Resistor |  | 6k8 | 0.1W | SMD0603 | R114-1, R114-2 | 2 | 2 | 4 |  | YAGEO
Resistor array | YC248 | 33 | 0.062W | YC248 | RA1, RA2, RA3 | 3 | 16 | 48 |  | Yageo
LED SMD RIGHT ANGLE | APA-1606CGCK | GREEN | 110 deg | SMD1606 | LED1A', LED1B', LED1C', LED2A', LED2B', LED2C', LED3A', LED3B', LED3C' | 9 | 2 | 18 | 754-1051-1-ND (http://www.digikey.com/product-detail/en/APA1606CGCK/754-1051-1-ND/1747768) | Kingbright
LED SMD | LS Q976-NR-1 | RED |  | SMD0603 | LED4, LED5, LED6 | 3 | 2 | 6 | 475-2512-1-ND | OSRAM Opto Semi.
Transistor | BC817-40 |  |  | SOT23 | Q4 | 1 | 3 | 3 |  | Philips
Transistor | BCP69 |  |  | SOT-223 | Q3 | 1 | 4 | 4 |  | INFINEON
Transistor | FDV301N |  |  | SOT23 | Q1, Q2 | 2 | 3 | 6 |  | Fairchild
Transformer | TC1-1-13MG2 |  |  | AT224-1 | T1-1, T1-2, T2-1, T2-2 | 4 | 4 | 16 |  | Mini-Cirquits
Transformer | TC4-25+ |  |  | AT224-1 | T3-1, T3-2 | 2 | 5 | 10 |  | Mini-Cirquits
ESD filter | NFM3DPC223R1H3 |  |  | NFM3DP | Z1-1, Z1-2 | 2 | 3 | 6 |  | Murata
 |  |  |  |  |  |  | Total pins: | 2447
Through hole components
Description | Name | Value | U/P/TKE | Footprint | Designator | Quantity | Pins | Total | Lynk | Manufacturer
Connector for FAN | CONN HEADER 2POS .100 VERT |  |  | Any 2.54mm | X17, X18 | 2 | 2 | 4 | WM4111-ND (http://www.digikey.com/product-detail/en/0022272021/WM4111-ND/1130577) | According to FAN
RJ45 GBEth connector vs ferrite | RJ45 1840710-1 |  | -40`C | RJ45 1840710-x | X4 | 1 | 15 | 15 | 1840710-1-ND | Tyco Electronics AMP
 |  |  |  |  |  |  | Total pins: | 19
Other components
Description | Name | Value | U/P/TKE | Footprint | Refer to | Quantity | Pins | Total | Lynk | Manufacturer
MCX/SMA-F Cable | AC-M03RA-S01BH-316-15 | 150mm |  |  | X8, X9, X10, X11, X14, X15 | 6 |  |  | MCX to SMA (http://www.rfsupplier.com/male-right-angle-female-bulkhead-pigtail-cable-p-354.html) | RF Supplier
Thermal pads sheet, tacky | TG4040-150-150-5.0-0 | 150x150x5mm sheet | 4.0 W/m-K | 15x15mm at bottom for IC's --> | U8, U9, U12-1, U12-2, U34 | 5 |  |  | TG4040-150-150-5.0-0 (http://www.digikey.com/product-detail/en/TG4040-150-150-5.0-0/1168-1339-ND/3042168) | T-Global Technology

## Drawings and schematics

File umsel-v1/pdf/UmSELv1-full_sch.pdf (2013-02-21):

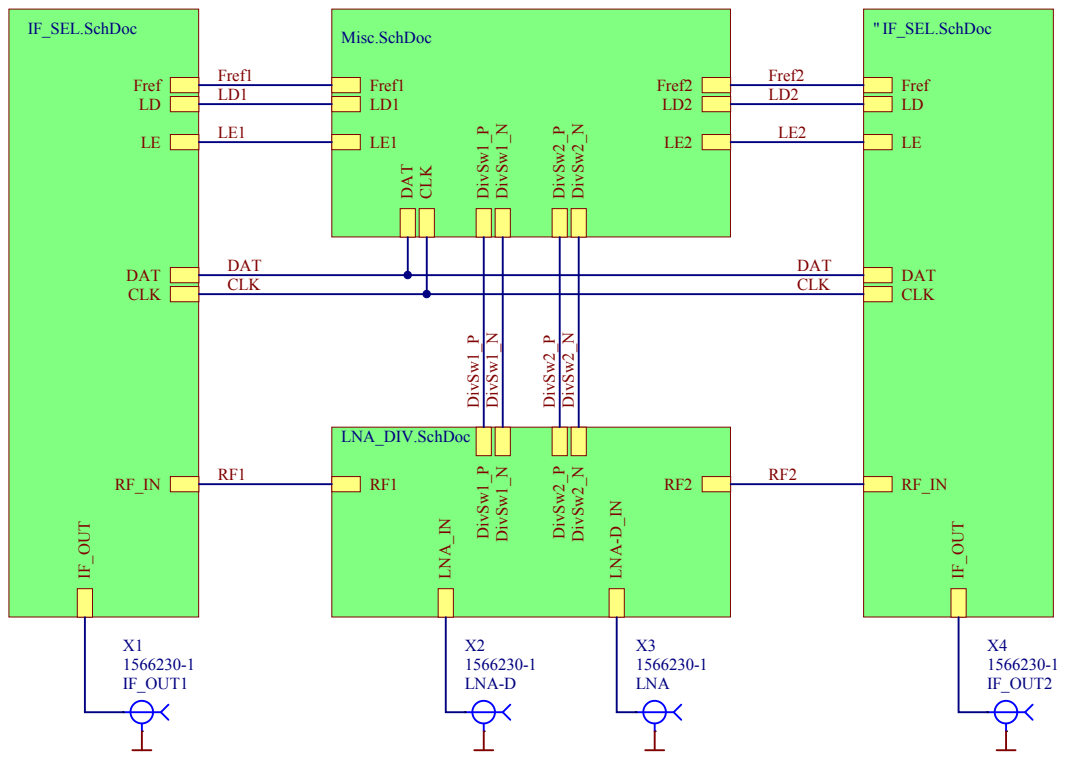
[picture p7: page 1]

DAT
CLK | CLK

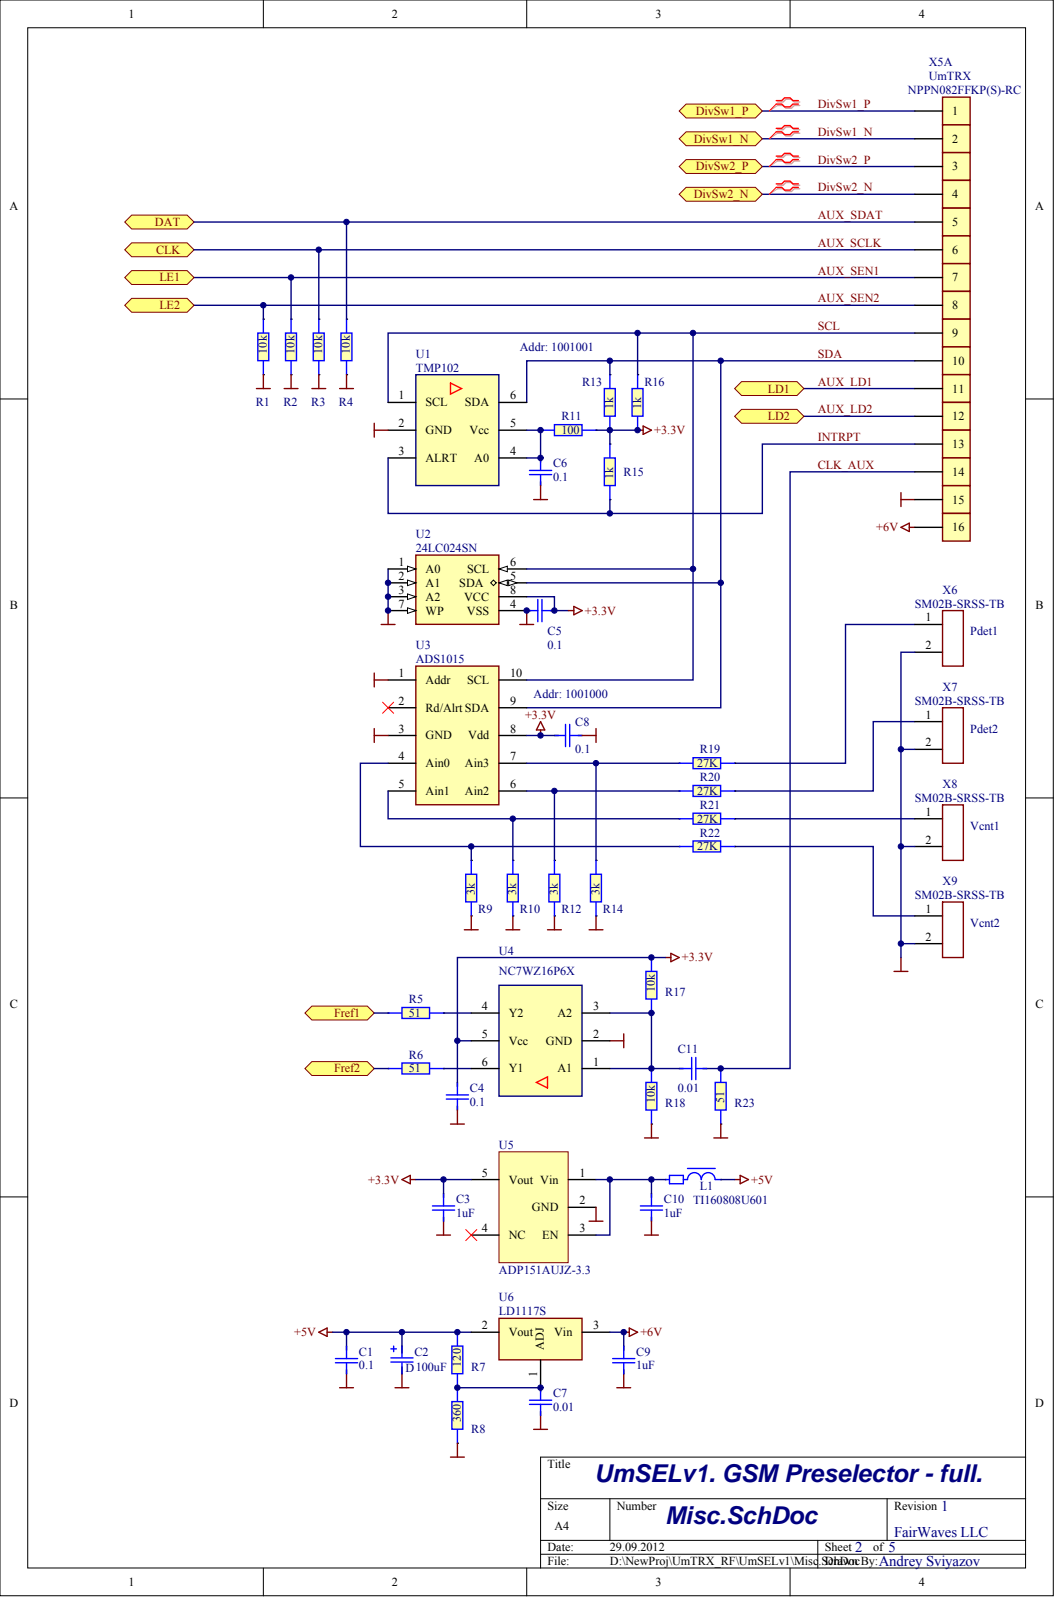
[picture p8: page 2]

Addr: 1001001 U1 TMP102 | | SDA

AUX_LD1 LD1

GND 2 Vcc | 5 | | | AUX_LD2 LD2 INTRPT | 12

Rd/Alrt 2 | | Addr: 1001000
GND 3 | +3.3V C8 R19

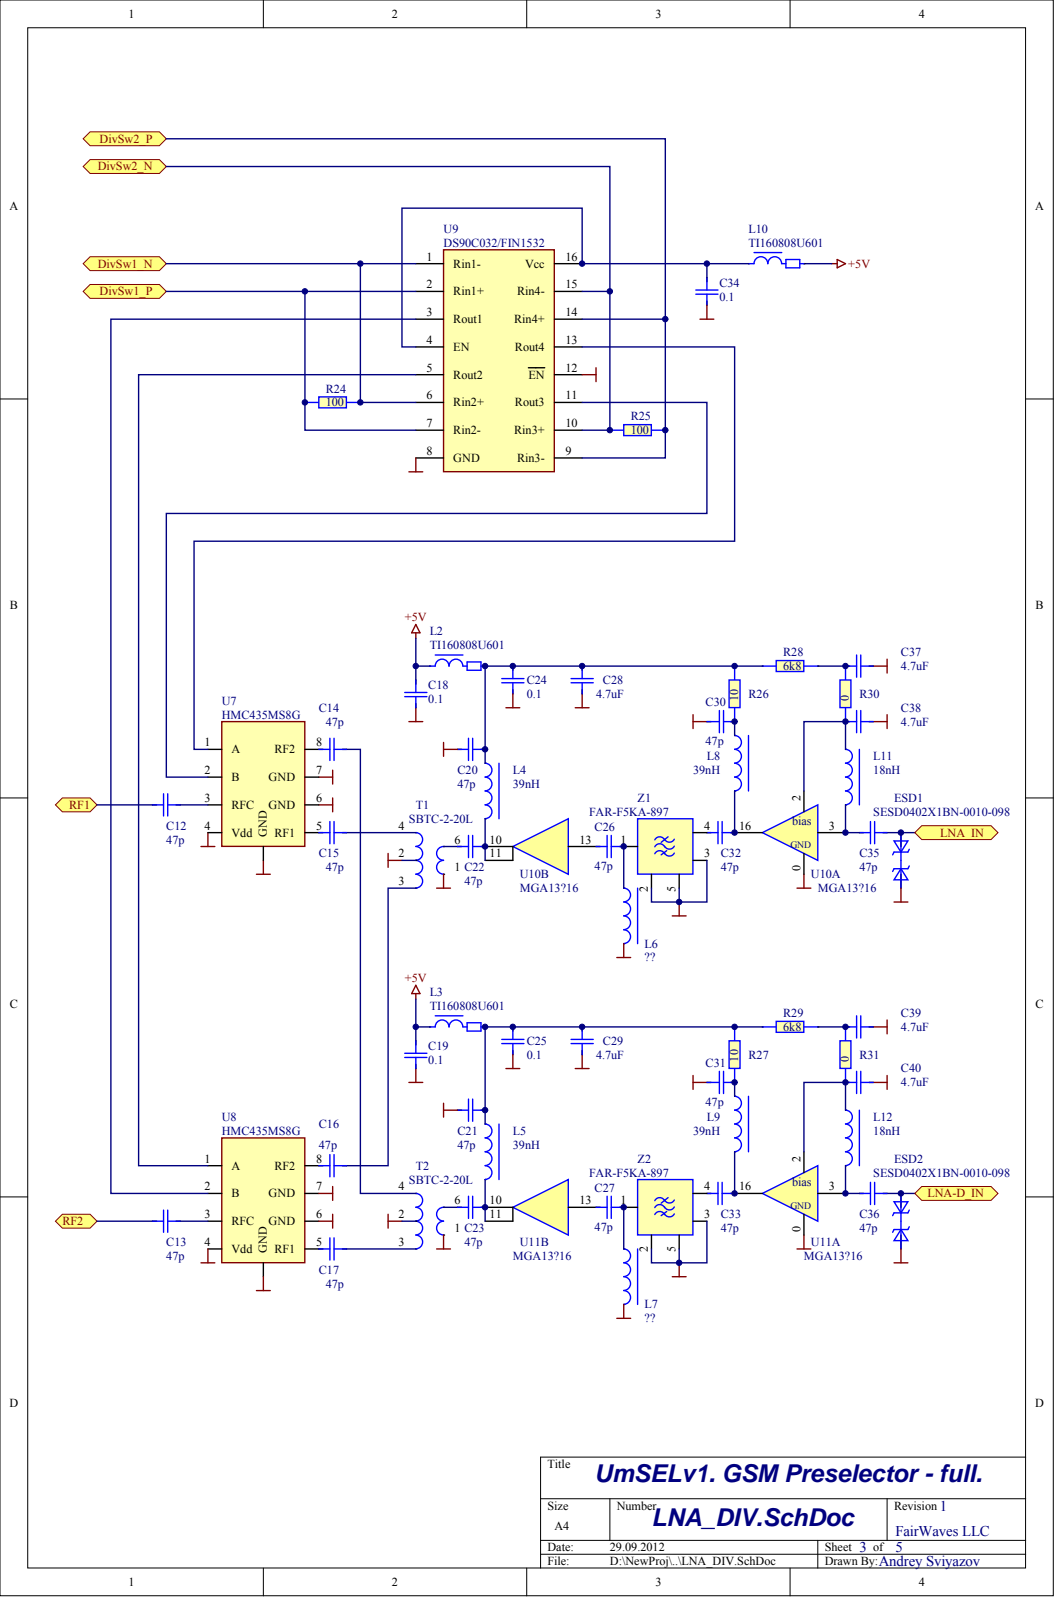
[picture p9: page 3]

Rin1+ 2

Rout1 3 Rin4+ | 14

EN 4 Rout4 EN Rout3 Rin3+ | 13

Rout2 5 | 12

R24 | Rin2+ 6 | 11

Rin2- 7 | 10 | R25

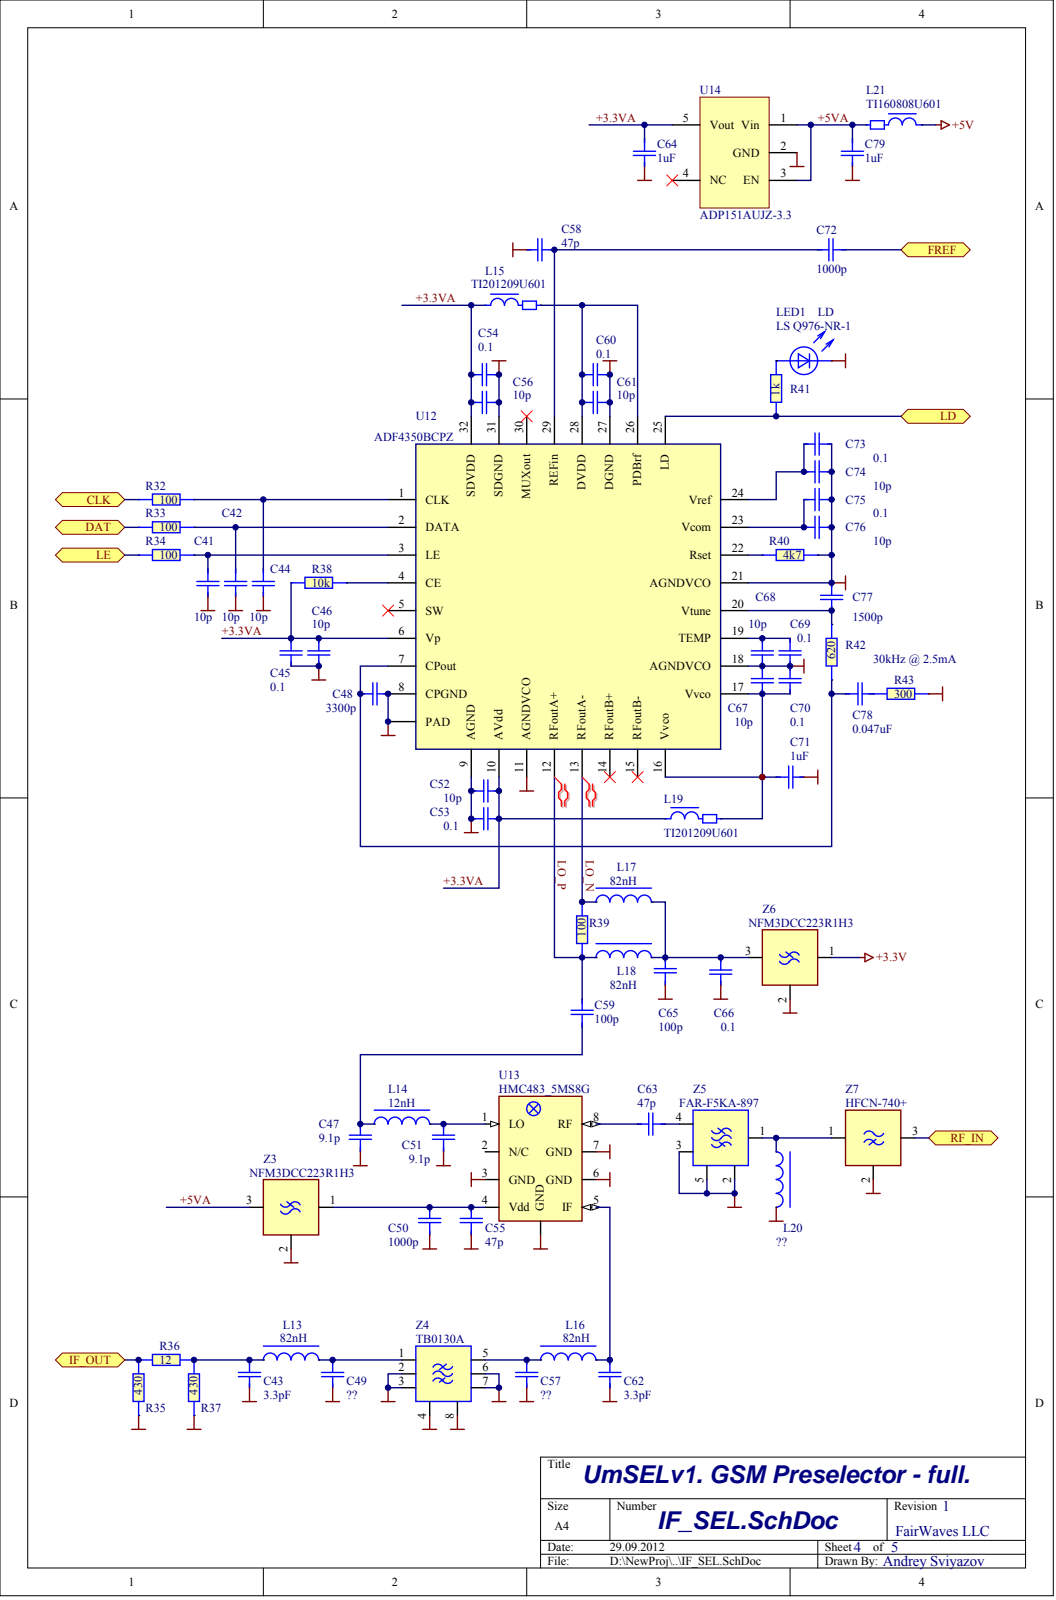
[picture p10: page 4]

CPout 7

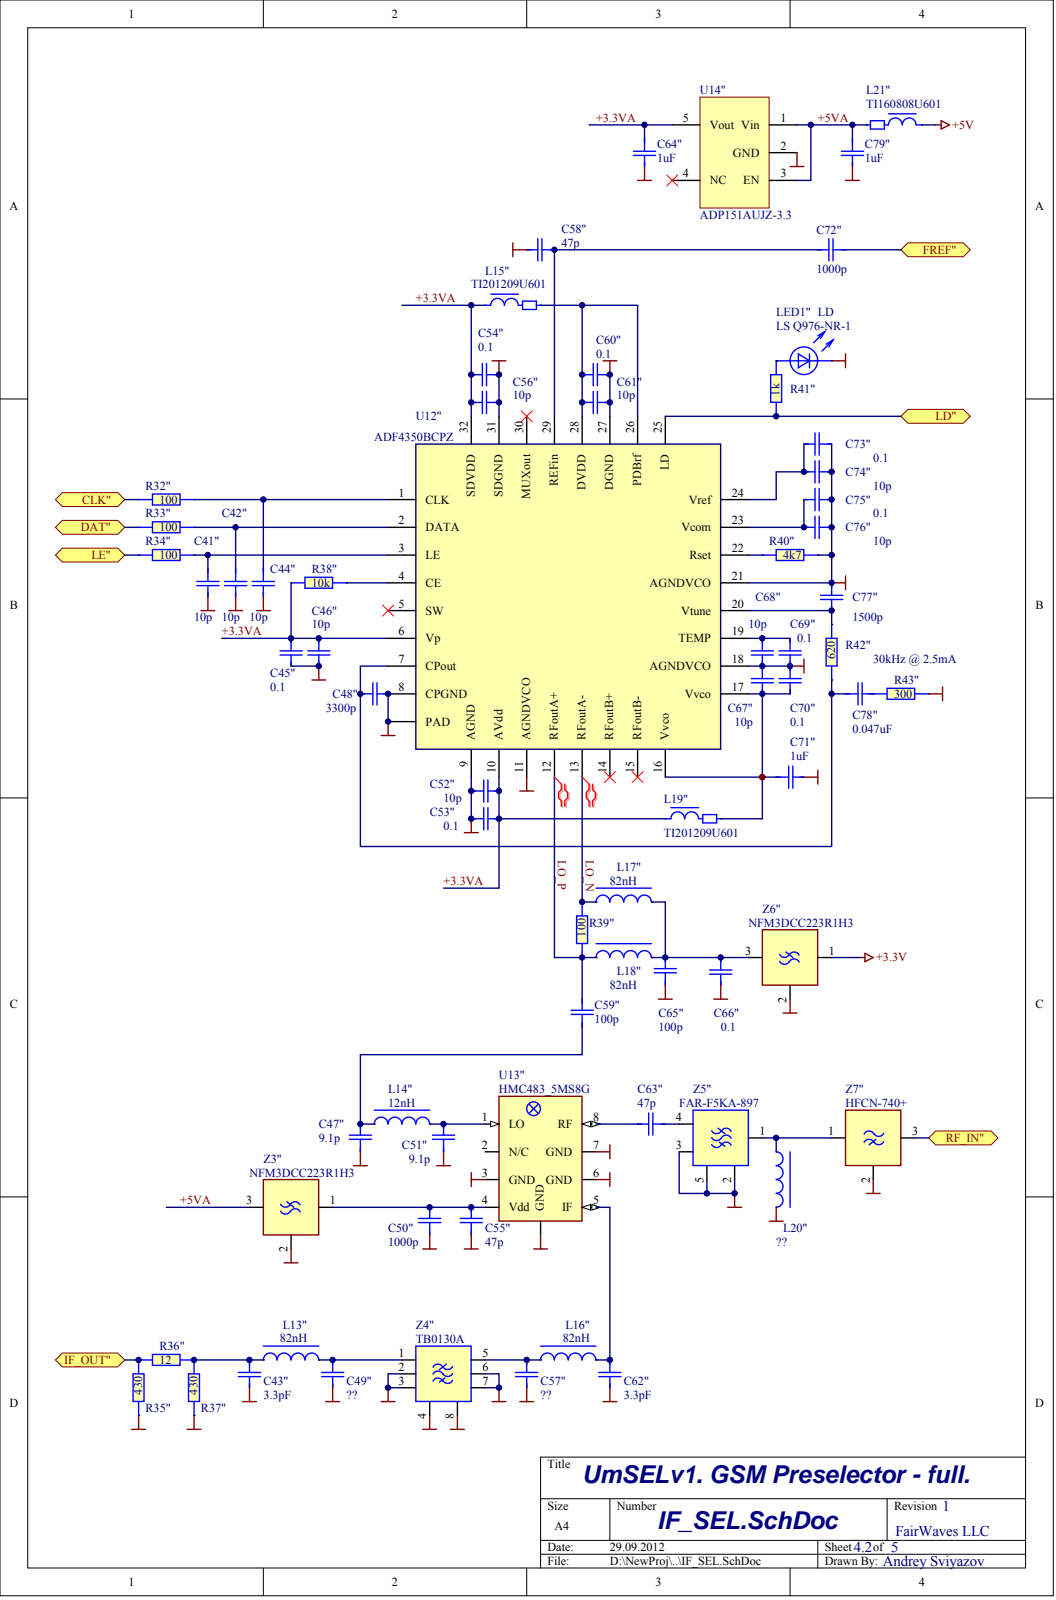
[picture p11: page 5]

CPout 7

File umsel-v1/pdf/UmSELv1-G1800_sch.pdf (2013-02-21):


DAT
CLK | CLK

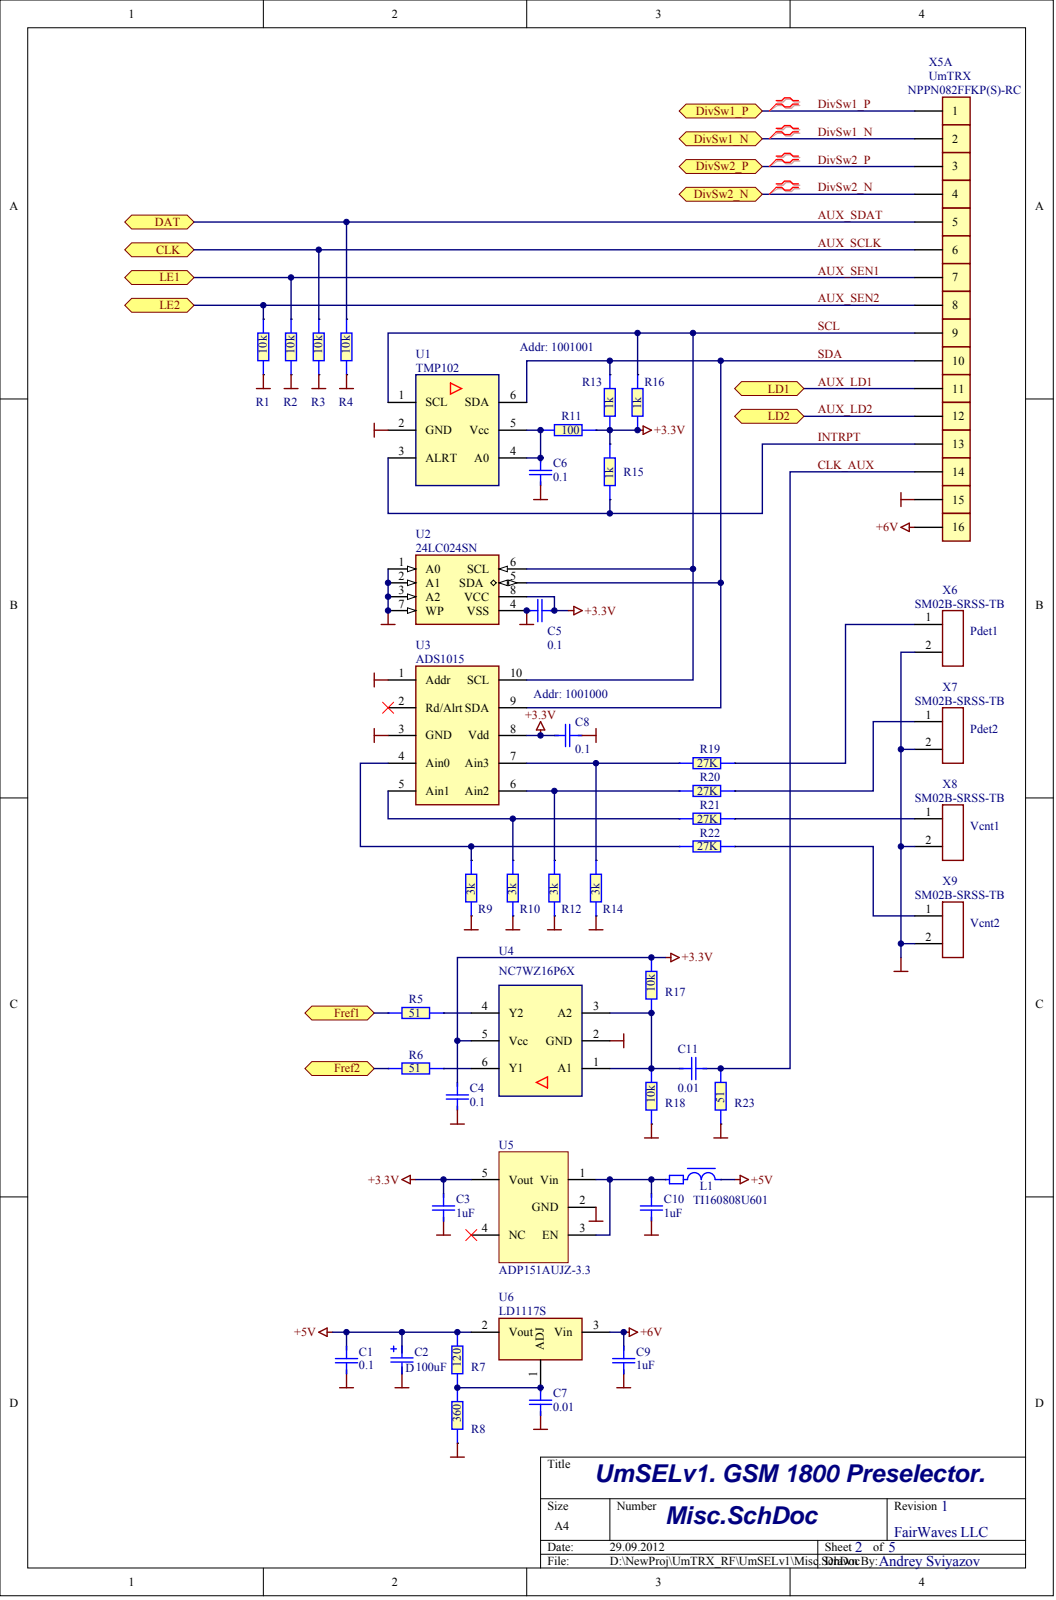
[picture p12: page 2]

Addr: 1001001 U1 TMP102 | | SDA

AUX_LD1 LD1

GND 2 Vcc | 5 | | | AUX_LD2 LD2 INTRPT | 12

Rd/Alrt 2 | | Addr: 1001000
GND 3 | +3.3V C8 R19

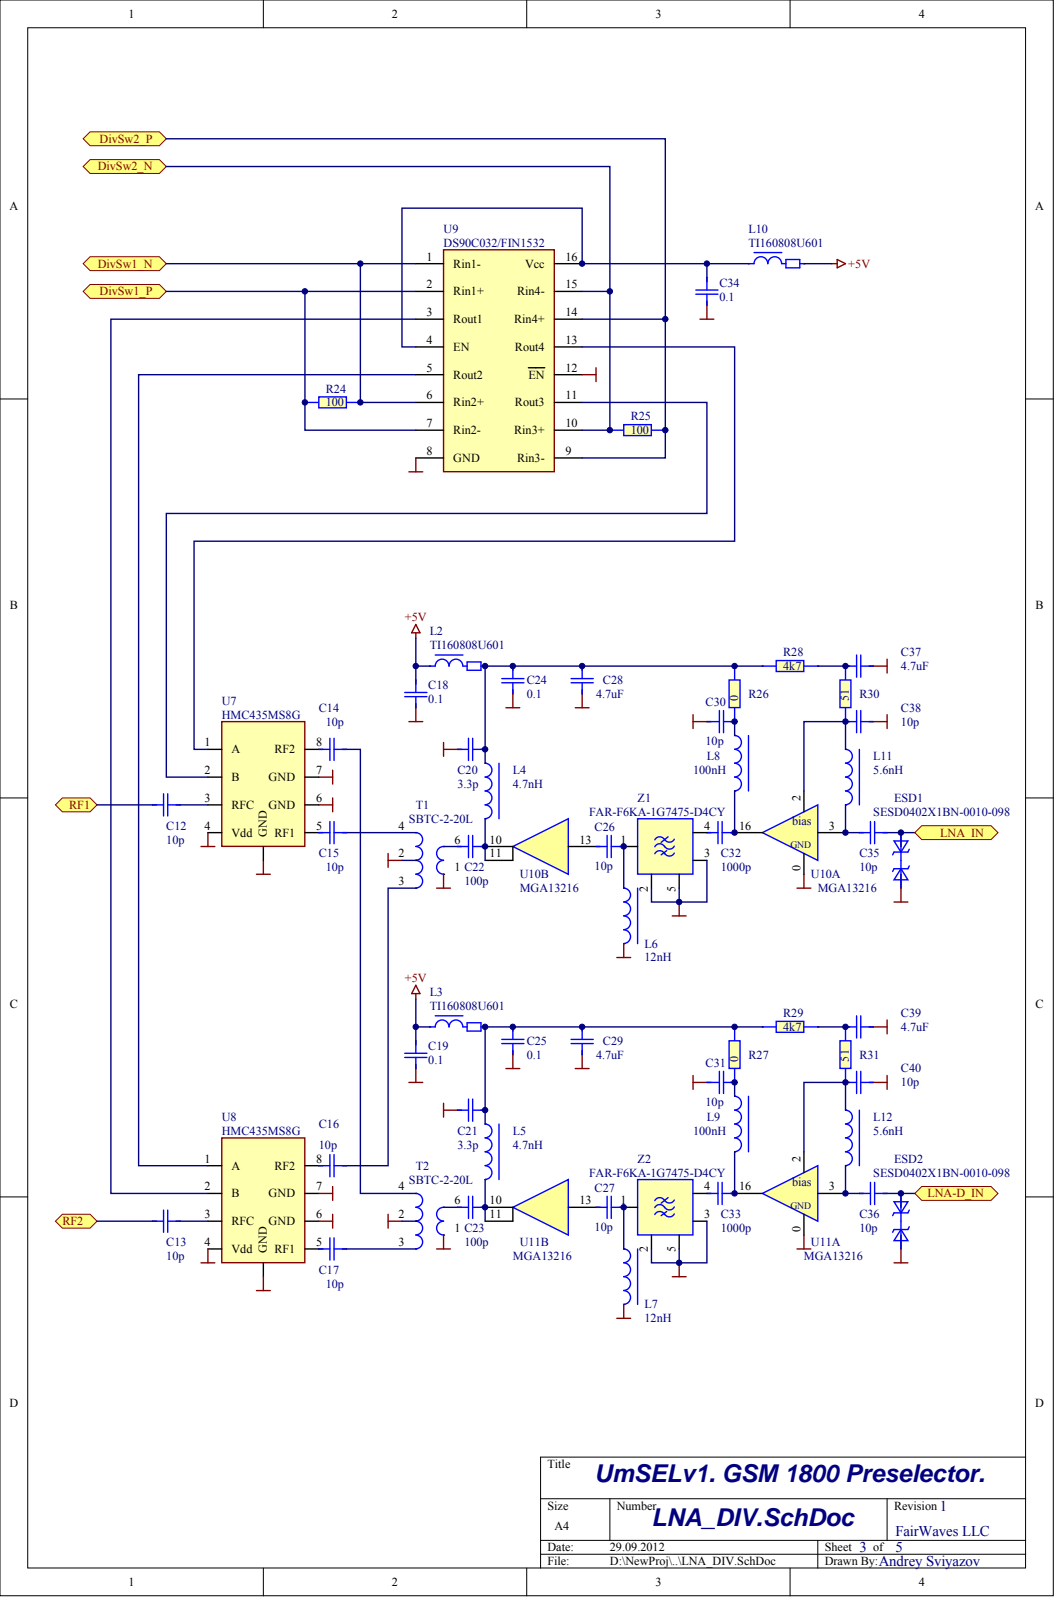
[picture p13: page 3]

Rin1+ 2

Rout1 3 Rin4+ | 14

EN 4 Rout4 EN Rout3 Rin3+ | 13

Rout2 5 | 12

R24 | Rin2+ 6 | 11

Rin2- 7 | 10 | R25

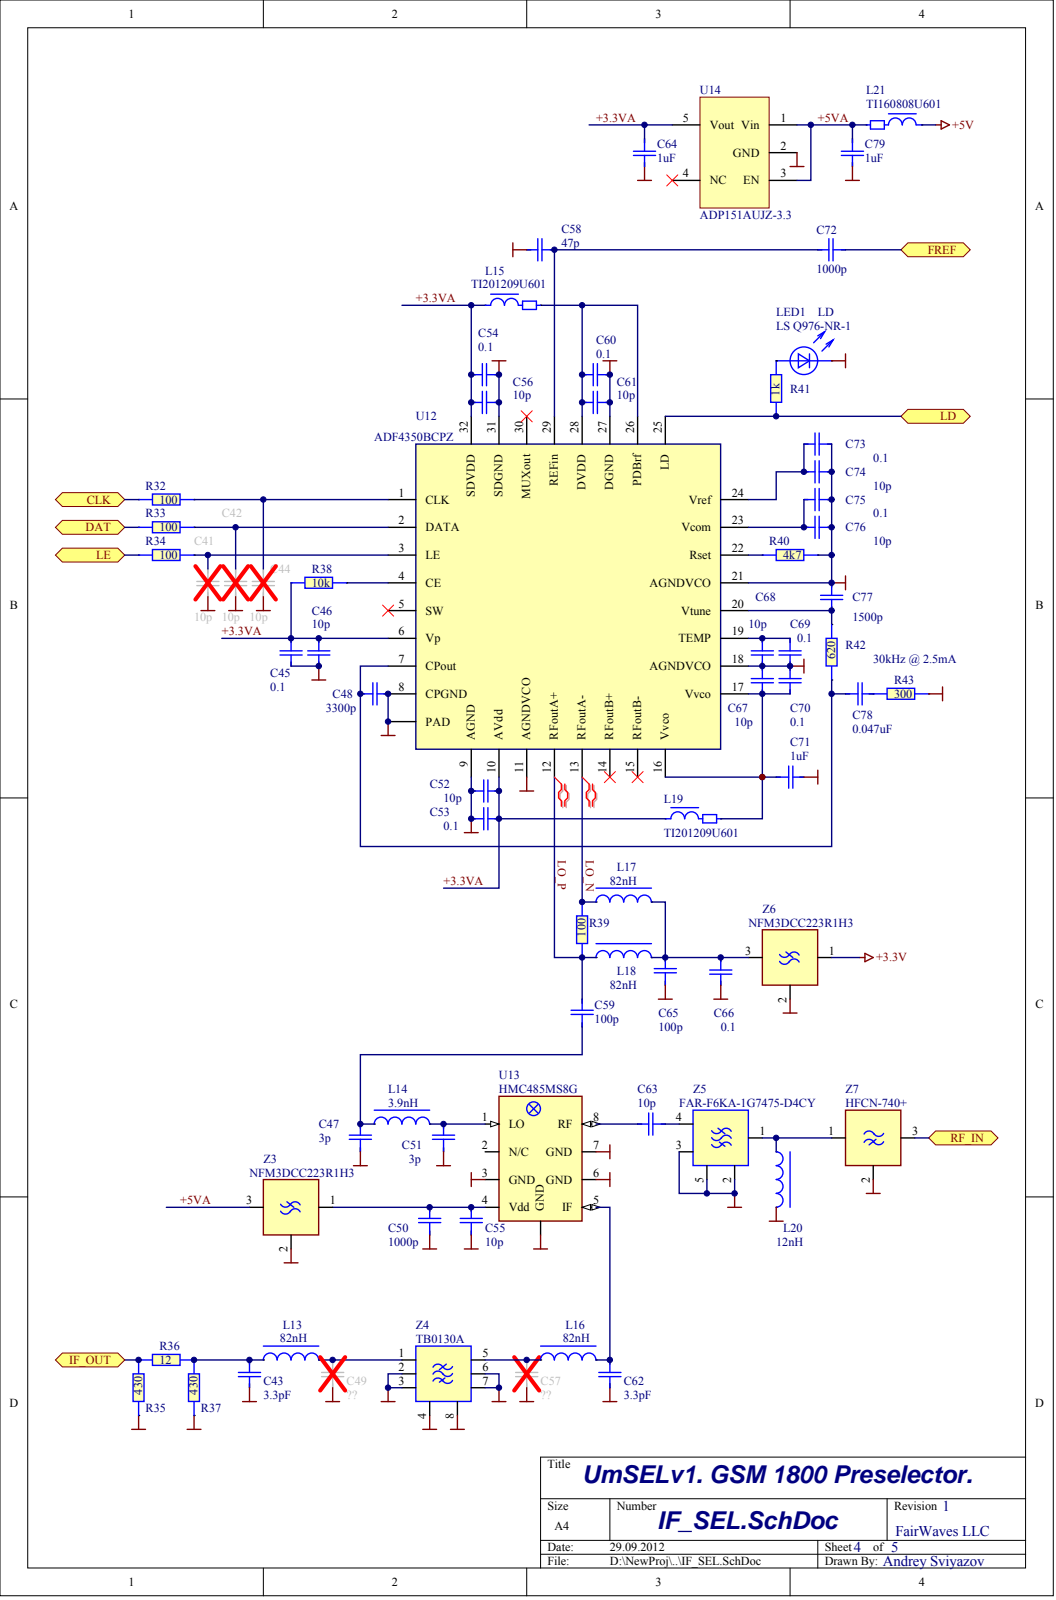
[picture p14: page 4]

CPout 7

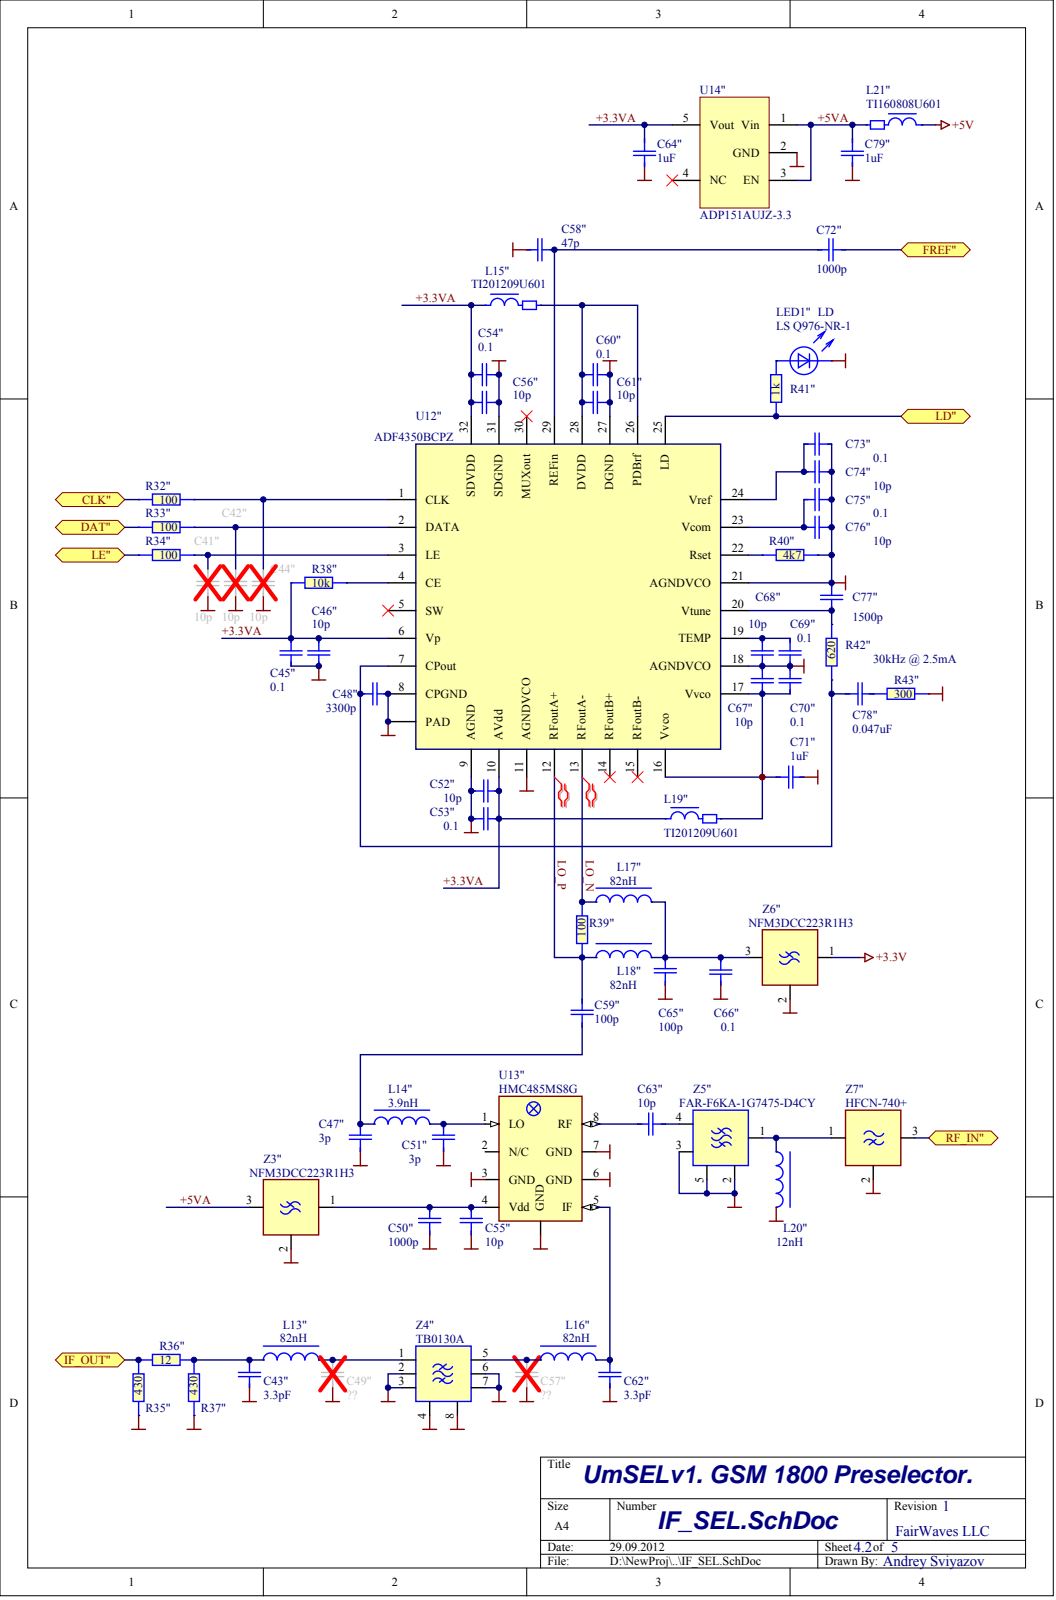
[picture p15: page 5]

CPout 7

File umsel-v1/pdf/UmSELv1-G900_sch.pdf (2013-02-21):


DAT
CLK | CLK

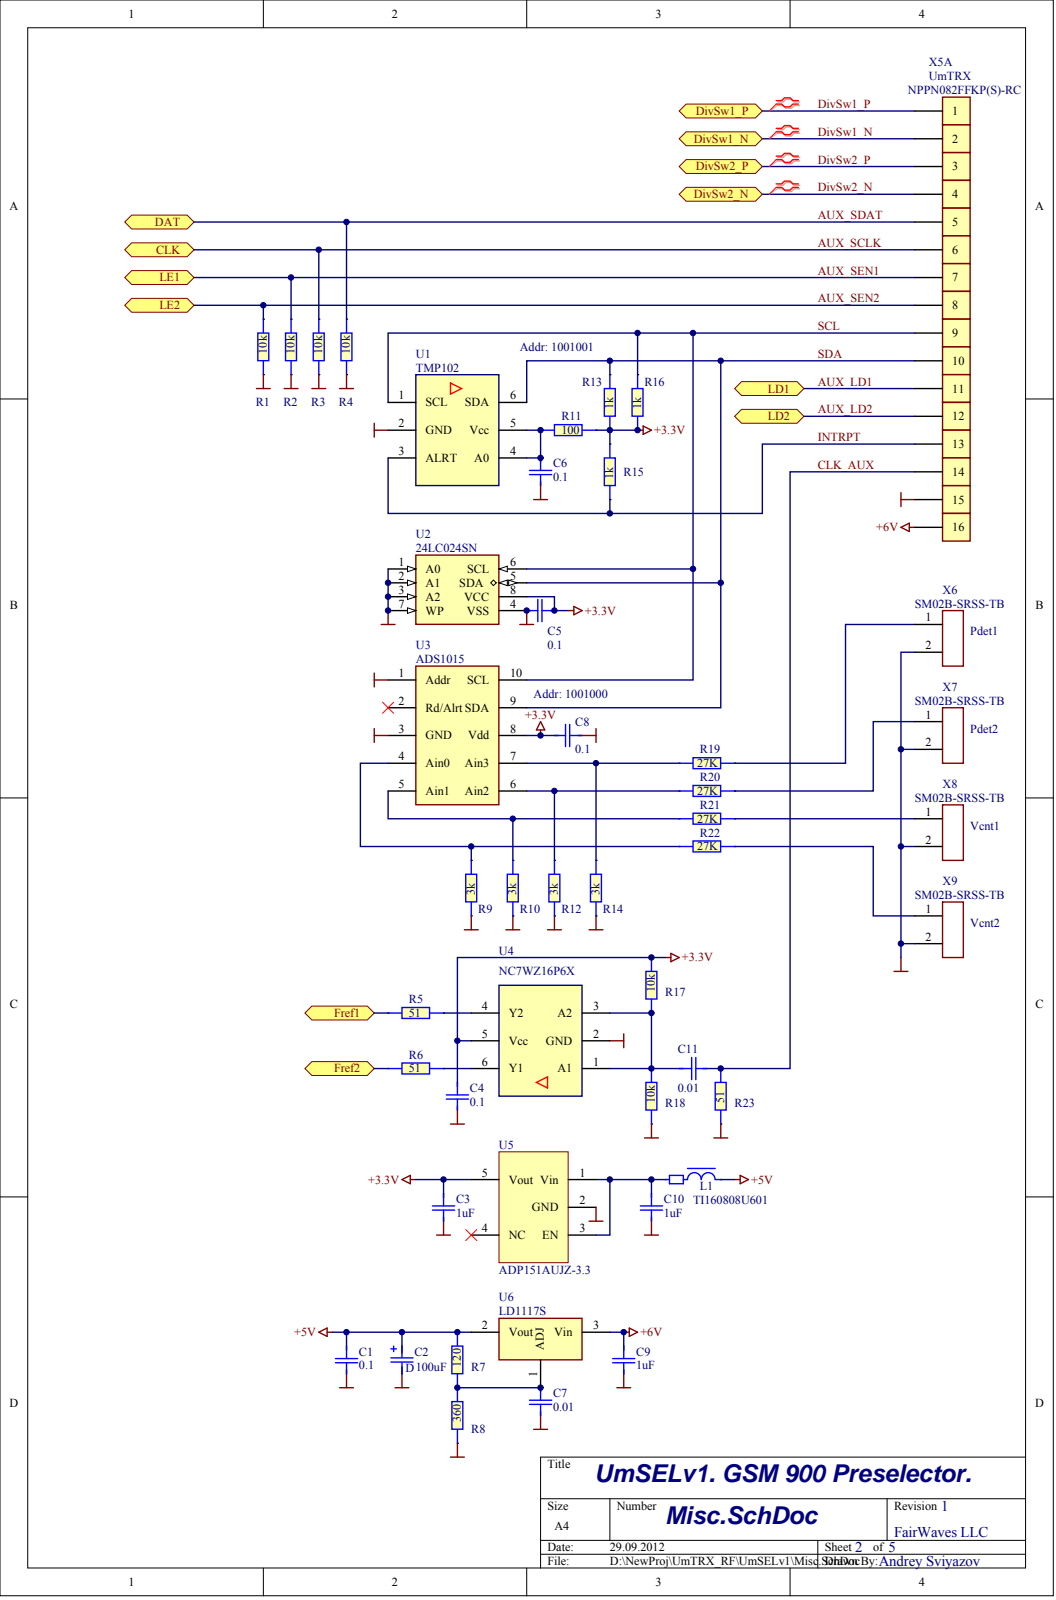
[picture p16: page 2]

Addr: 1001001 U1 TMP102 | | SDA

AUX_LD1 LD1

GND 2 Vcc | 5 | | | AUX_LD2 LD2 INTRPT | 12

Rd/Alrt 2 | | Addr: 1001000
GND 3 | +3.3V C8 R19

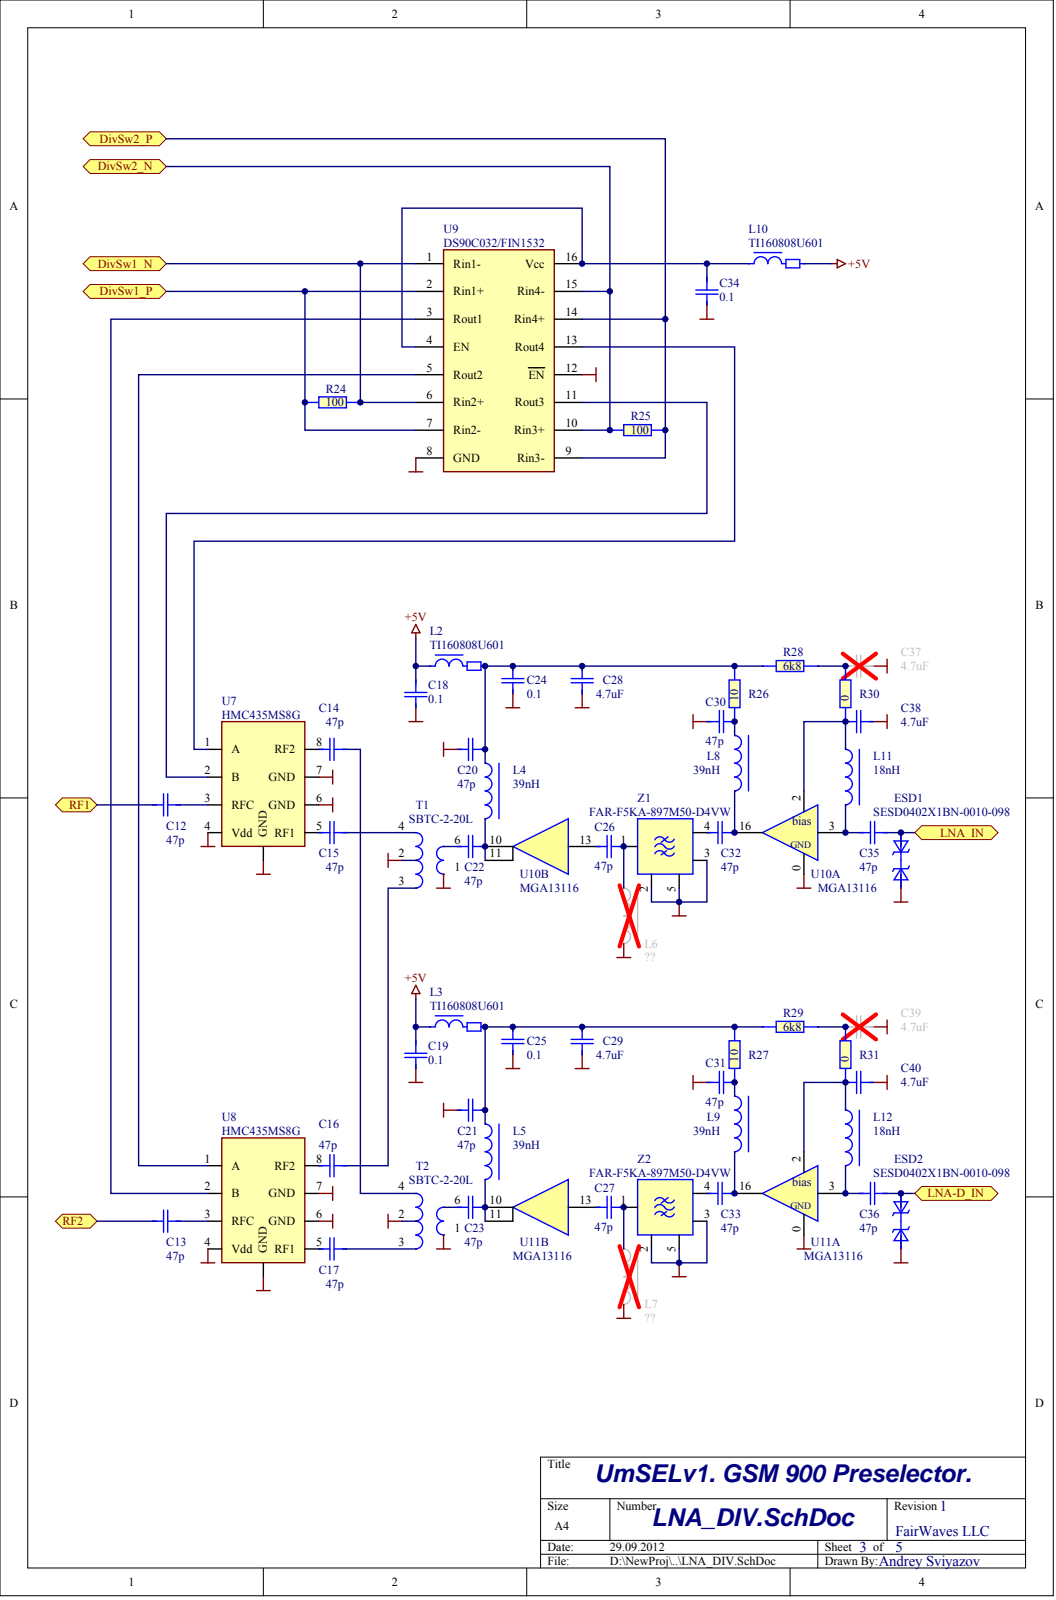
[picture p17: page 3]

Rin1+ 2

Rout1 3 Rin4+ | 14

EN 4 Rout4 EN Rout3 Rin3+ | 13

Rout2 5 | 12

R24 | Rin2+ 6 | 11

Rin2- 7 | 10 | R25

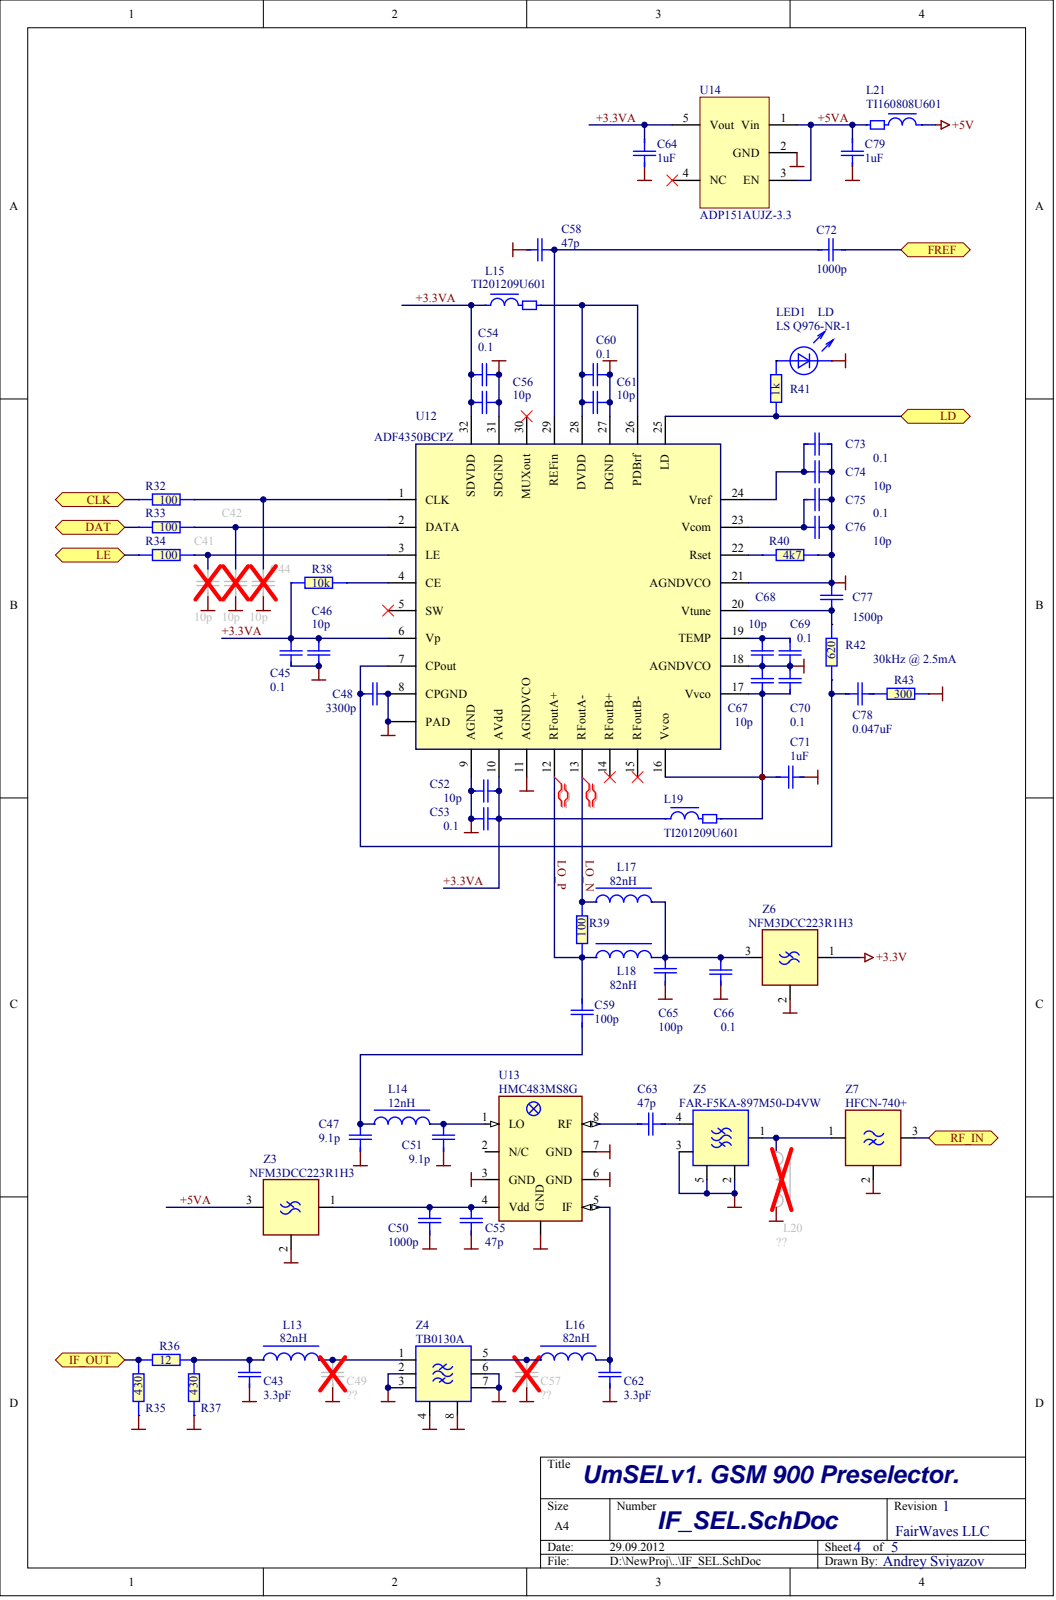
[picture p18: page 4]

CPout 7


CPout 7

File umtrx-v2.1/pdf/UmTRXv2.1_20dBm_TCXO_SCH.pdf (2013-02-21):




TXOUT2N 46 | ??

U38-1 Address: 1001010/1001011

+3,3VLMS-1

3k3 | XRES12k 89 | 3k3

12k R107-1 390 | R114-1 | XRESAD 39


TXOUT2N 46 | ??

U38-2 Address: 1001010/1001011

+3,3VLMS-2

3k3 | XRES12k 89 | 3k3

12k R107-2 390 | R114-2 | XRESAD 39


26MHZ
Dn - MASTER Up - SLAVE

1PPS

1 | LED3A | 6


6 | TRD3_N 38


LED1
LED1B' APA-1606CGCK LED1C' APA-1606CGCK LED2A' APA-1606CGCK LED2B' APA-1606CGCK LED2C' APA-1606CGCK LED3C' APA-1606CGCK


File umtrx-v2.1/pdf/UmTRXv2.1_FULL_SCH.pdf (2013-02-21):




TXOUT2N 46 | ??

U38-1 Address: 1001010/1001011

+3,3VLMS-1

3k3 | XRES12k 89 | 3k3

12k R107-1 390 | R114-1 | XRESAD 39


TXOUT2N 46 | ??

U38-2 Address: 1001010/1001011

+3,3VLMS-2

3k3 | XRES12k 89 | 3k3

12k R107-2 390 | R114-2 | XRESAD 39


26MHZ
Dn - MASTER Up - SLAVE

1PPS

1 | LED3A | 6


6 | TRD3_N 38


LED1
LED1B' APA-1606CGCK LED1C' APA-1606CGCK LED2A' APA-1606CGCK LED2B' APA-1606CGCK LED2C' APA-1606CGCK LED3C' APA-1606CGCK


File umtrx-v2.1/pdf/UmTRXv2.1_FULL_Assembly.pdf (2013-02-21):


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

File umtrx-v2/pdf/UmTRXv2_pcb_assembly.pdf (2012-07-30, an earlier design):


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

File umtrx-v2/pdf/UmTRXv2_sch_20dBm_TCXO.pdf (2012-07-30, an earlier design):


SEN MISO MOSI SCLK



TXOUT2N 46 | ??

51 | TXCPOUT 64


TXOUT2N 46 | ??

51 | TXCPOUT 64


RSVD_GND 4

26MHZ
Dn - MASTER Up - SLAVE

1PPS

1 | | LED3A | 6


Gre e n | 0 R4 4


USBDM USBDP RE SET OSCI OSCO | 5 | 1


F 4 | P 9
F 6 | 4

1 1 | 1
2 0 | 1
2 7 | 2 1
5 4 | 2

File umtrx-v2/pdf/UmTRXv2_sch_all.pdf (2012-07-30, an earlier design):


SEN MISO MOSI SCLK



TXOUT2N 46 | ??

51 | TXCPOUT 64


TXOUT2N 46 | ??

51 | TXCPOUT 64


RSVD_GND 4

26MHZ
Dn - MASTER Up - SLAVE

1PPS

1 | | LED3A | 6


Gre e n | 0 R4 4


USBDM USBDP RE SET OSCI OSCO | 5 | 1


F 4 | P 9
F 6 | 4

1 1 | 1
2 0 | 1
2 7 | 2 1
5 4 | 2

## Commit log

2012-07-15 UmTRXv2: Initial check-in of schematics and BoM.
    PCB layout is not available yet and will be checked in with the UmTRX sales start.
    [Clocking.SchDoc, EEpromConfig.SchDoc, FPGA_RAM.SchDoc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]
2012-07-30 Improve LMS noise figures, introducing AC coupling for PLLCLK and changing PLL filter to 100kHz.
    List of components which are changed:
    L6-1, L6-2 = R0603 0 Ohm instead of choke
    C45-1, C45-2 = Do Not Install
    C82-1, C82-2, C98-1, C98-2 = 100pF instead of 470pF
    C83-1, C83-2, C99-1, C99-2 = 1500pF instead of 8.2nF
    C84-1, C84-2, C97-1, C97-2 = 33pF instead of 150pF
    R106-1, R106-2, R121-1, R121-2 = 2k2 instead of 820 Ohm
    R109-1, R109-2, R119-1, R119-2 = 3k3 instead of 1.2 kOhm
    This closes Issue 30:
    http://code.google.com/p/umtrx/issues/detail?id=30
    [LMS.SchDoc, PwrAndBias.SchDoc, Total.SchDoc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]
2012-08-08 Renamed "umtrxv2" directory to "umtrx-v2".
    [Clocking.SchDoc, EEpromConfig.SchDoc, FPGA_RAM.SchDoc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]
2012-08-08 Checking in design files for he UmTRXv2 preselector board.
    [IF_SEL.SchDoc, LNA_DIV.SchDoc, Misc.SchDoc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]
2012-08-25 Files for the preselector frontend updated.
    * The board is renamed to UmSEL
    * Schematics updated
    * Board layout is published
    * 3D pictures of the board are published
    [IF_SEL.SchDoc, LNA_DIV.SchDoc, Misc.SchDoc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]
2012-09-19 Checking in a photo of UmTRXv2 board.
2012-09-30 A lot fixes, additions and updates.
    * Added four channels ADC (i2c) IC to measure power leves of two PA's and two control points of DC plant.
    * Schematic PDF files generated for GSM900 and GSM1800 variants.
    * Gerber files updated.
    * NC Drill files re-created with Altium default names.
    * Pick & Place files generated for GSM900 and GSM1800 variants.
    [BOM UmSELv1-GSM1800.xls, BOM UmSELv1-GSM900.xls, IF_SEL.SchDoc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]
2012-12-04 Renamed directory umtrx-v2-rxsel -> umsel-v1.
    [BOM UmSELv1-GSM1800.xls, BOM UmSELv1-GSM900.xls, IF_SEL.SchDoc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]
2012-12-04 Checking in UmTRXv2.1 schematics.
    [Clocking.SchDoc, EEpromConfig.SchDoc, FPGA_RAM.SchDoc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]
2013-02-21 Checking in BOM files for UmSELv1 in other formats required by the fab.
    [BOM UmSELv1-GSM1800 PnP.xls, BOM UmSELv1-GSM1800 by RefDes.xls, BOM UmSELv1-GSM900 PnP.xls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]
2013-04-20 Checking in PCB layout files for UmTRX v2.0 and UmTRX v2.1.
